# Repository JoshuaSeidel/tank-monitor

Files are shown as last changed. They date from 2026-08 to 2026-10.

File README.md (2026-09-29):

# Tank Monitor

An ESP32-C6 aquarium controller: water temperature, TDS, and light level, with a
**self-learning predictive thermostat** that drives a heater and a cooling fan.
Reports to Home Assistant over MQTT with auto-discovery.

The control loop runs entirely on the ESP32. Home Assistant gets the data and
a setpoint slider, but if HA reboots, updates, or falls off the network, the
tank keeps being regulated exactly as before.

---

## Why the temperature swings 73–76 °F

A stock aquarium heater is a bimetallic on/off switch with roughly 2 °F of
hysteresis. It heats until it's over target, shuts off, the tank coasts down
past target, and it kicks on again. Add the daylight/lights heat load on top
and you get the 3 °F band you're seeing.

Two things here fix that:

1. **Time-proportional output.** Instead of on/off, the heater is switched on
   for a fraction of each 15-minute window. 30% duty is 30% of full heater
   power, so the tank can sit *at* the setpoint instead of oscillating around
   it. (Set the heater's own thermostat dial to its maximum and let this
   control it — the heater becomes a dumb resistor.)

2. **Feed-forward from a learned model.** The controller knows how fast your
   specific tank heats, cools, and gains heat from the lights, so it backs the
   heater off *before* the lights warm the water rather than after.

Expect ±0.5 °F once the model has a day of data — or ±0.2 °F if you swap the
heater onto an SSR and shorten the window (see below).

---

## Board

Built for a **LAFVIN / Waveshare ESP32-C6-LCD-1.47** — ESP32-C6 with an
on-board 1.47" 172x320 ST7789V panel. ESPHome ships a preset for this exact
board (`model: WAVESHARE-ESP32-C6-LCD-1.47`), which supplies the panel's
CS/DC/reset pins, its 34 px column offset, and colour inversion.

The display driver is `mipi_spi`, not the older `st7789v` platform. With a
90 degree rotation the old driver wants a full framebuffer and the C6 — 512 KB
SRAM, no PSRAM — runs out of memory. Current build sits at **35% RAM, 66%
flash**, so there's headroom but not unlimited.

The screen shows water temperature, target, heater and fan duty bars, TDS,
light level, and controller state. It keeps working when Home Assistant
doesn't, which is the whole point of running the control loop on-device.

### Pins already taken by the board

The LAFVIN breaks out two header rows, and **only these pins are physically
available**:

| Edge | Pins |
|---|---|
| One long edge | `9, 18, 19, 20, 23, 22, 13, RX, TX` |
| Other long edge | `5, 4, 3, 2, 1, 0, 3V3, GND, 5V` |

**GPIO10 is not on the board** — anything assigned to it silently does
nothing. Avoid `22` as well (exposed, but it's also the LCD backlight net),
`13` (USB D+), and `9` (boot strapping pin). GPIO6/7 are the LCD SPI bus and
14/15/21 are its CS/DC/reset, none of which reach a header.

## Parts list

Manufacturer links are verified. Amazon entries are **searches**, not
specific listings — ASINs for commodity parts churn constantly and a dead
link is worse than none.

### Required — the controller

| Part | Notes | Where |
|---|---|---|
| **LAFVIN / Waveshare ESP32-C6-LCD-1.47** | the controller and its display. Any ESP32 works — see `boards/` | [search](https://www.amazon.com/s?k=ESP32-C6+1.47+inch+LCD+development+board) |
| **DS18B20 waterproof probe** | water temperature. The one measurement the whole control loop depends on | [search](https://www.amazon.com/s?k=DS18B20+waterproof+temperature+probe) |
| **4.7 kΩ resistor, ¼ W** | **required** pull-up for the DS18B20, and the one part that arrives in none of the boxes | [assortment kit](https://www.amazon.com/Resistor-Assortment-Resistance-Electric-Projects/dp/B07N1ZK8CC) |
| **CZH-Labs D-1584TL** | 2-channel relay outlet module, ~$49. Two *independently* switched outlets — a single-channel IoT Relay cannot run a heater and a fan | [Amazon](https://www.amazon.com/Two-Channel-Control-Module-Arduino-Raspberry/dp/B0GR85JF68) · [direct](https://czh-labs.com/products/ac-power-2-channel-iot-relay-outlet-module-din-rail-or-screw-mounting) |
| 26–28 AWG stranded wire | hookup, silicone jacket is easiest | [search](https://www.amazon.com/s?k=26+AWG+silicone+stranded+hookup+wire) |
| Heat shrink, 2 mm and 3 mm | joints and splices | [search](https://www.amazon.com/s?k=heat+shrink+tubing+assortment+2mm+3mm) |

### Strongly recommended — pH

The controller cannot regulate what it cannot measure, and pH is the number
that tells you whether CO₂ is safe. **Buy the industrial version**: the
standard Gravity kit's electrode is not rated for permanent immersion, which
DFRobot themselves will tell you if you ask.

| Part | Notes | Where |
|---|---|---|
| **DFRobot SEN0169-V2**, *wide voltage* edition | $64.90. 3.3–5.5 V supply and **0–3 V output** — the classic edition outputs 0–5 V and would damage an ESP32 ADC pin | [DFRobot](https://www.dfrobot.com/product-2069.html) · [wiki](https://wiki.dfrobot.com/sen0169-v2/) |
| **pH 4.00 / 6.86 / 9.18 buffer sachets** (the NIST set) | the sensor is meaningless uncalibrated. Calibrate on the two that bracket the tank (9.18 and 6.86), check against the third | [search](https://www.amazon.com/s?k=pH+4.00+6.86+9.18+calibration+buffer+solution+sachets) |
| **KCl storage solution** | the electrode must never dry out. A dried probe is a dead probe | [search](https://www.amazon.com/s?k=pH+probe+KCl+storage+solution) |
| Suction-cup probe holder | fixes angle and depth; the bulb must point down | [search](https://www.amazon.com/s?k=aquarium+pH+probe+holder+suction+cup) |

### Optional — the rest

| Part | What it buys you | Where |
|---|---|---|
| Keyestudio TDS meter | dissolved solids. Useful for *trend*, not absolute — it ships uncalibrated | [search](https://www.amazon.com/s?k=Keyestudio+TDS+meter+sensor) |
| GY-302 / BH1750 module | ambient light, which the model uses to pre-compensate for the lights' heat | [search](https://www.amazon.com/s?k=GY-302+BH1750+light+sensor+module) |
| ESP32-2432S028R "CYD" | a second board as a remote touch panel — see `boards/cyd-esp32-2432s028r.yaml` | [search](https://www.amazon.com/s?k=ESP32-2432S028R+CYD+2.8+inch+display) |
| Seachem Ammonia Alert | a passive colorimetric disc, ~$10, lasts a year. **The best value item on this page** — there is no usable electronic ammonia sensor for a tank | [search](https://www.amazon.com/s?k=Seachem+Ammonia+Alert) |
| TCS34725 colour sensor | reads that disc so the ESP32 can log and alarm on it | [search](https://www.amazon.com/s?k=TCS34725+RGB+color+sensor) |
| DFRobot ORP probe | oxidation-reduction potential — the only practical measure of dissolved organic load. `GPIO33` is reserved for it on the WROOM-32 board, `GPIO4` on the S3 | [DFRobot](https://www.dfrobot.com/product-1071.html) |

### Test kits you cannot skip

No electronic sensor replaces these, and this project has twice chased a
phantom because a continuous reading was trusted over a liquid test.

| Kit | For |
|---|---|
| **API Freshwater Master Test Kit** | pH (low **and** high range), ammonia, nitrite, nitrate |
| **API GH & KH Test Kit** | sold separately. KH is what makes CO₂ injection safe or unsafe |

Test strips read GH and KH low and cannot resolve the range that matters
here. Use the drop tests.

### About the 4.7 kΩ resistor

**Anything from 2.2 kΩ to 10 kΩ works** — 4.7 kΩ is convention, not a
requirement. Check your DS18B20 first: some waterproof probes ship with a
small adapter board that already has one.

**If you don't have one yet**, the C6's internal pull-up will get you
through a bench test. Replace the `one_wire` block with:

```yaml
one_wire:
  - platform: gpio
    pin:
      number: GPIO18
      mode:
        input: true
        output: true
        open_drain: true
        pullup: true
```

It is roughly 45 kΩ, ten times weaker than spec. Fine on a short lead on the
bench; on a long waterproof probe cable it gives intermittent dropouts, which
this firmware reads as a probe fault and answers by cutting the heater.

## Wiring

Everything runs at 3.3 V.

### DS18B20 water temperature — 1-Wire

| Probe wire  | ESP32  |
|---|---|
| Red (VDD) | 3V3 |
| Black (GND) | GND |
| Yellow (DQ) | GPIO18 |

Add a **4.7 kΩ resistor between DQ and 3V3**. Not optional — the bus is
open-drain and reads garbage without it.

### Keyestudio TDS meter — analog

| Board pin | ESP32  |
|---|---|
| VCC | 3V3 |
| GND | GND |
| A (out) | GPIO1  |

Power the board at **3.3 V, not 5 V**. Feeding a 5 V-powered board's output
into a GPIO will damage the pin. If you must run it at 5 V, put a 10k/20k
divider on the output.

The C6 has a single ADC unit, so the classic ESP32 problem where ADC2 stops
working while Wi-Fi is up doesn't apply here. GPIO0 is the only other free
ADC pin — GPIO2 and GPIO3 now drive the relays, and the rest of the ADC
block (GPIO4-6) is taken by the microSD slot and LCD.

### GY-302 / BH1750 light sensor — I²C

| Module pin | ESP32 |
|---|---|
| VCC | 3V3 |
| GND | GND |
| SDA | GPIO19  |
| SCL | GPIO20  |
| ADDR | leave unconnected (address 0x23) |

Mount it where it sees the tank lighting *and* the room's daylight, but not
where it's shadowed by the hood at some hours and not others — the controller
learns a 24-hour light profile and a moving shadow shows up as fake noise.

Since your lights are touch-switched rather than scheduled, this sensor is
what tells the controller they're on. It learns their typical schedule too,
so it anticipates them; if you turn them on off-schedule, the live reading
still feeds the model within one control tick.

### Heater and fan — 2-channel relay outlet module

Built around the **CZH-Labs D-1584TL**, a 2-channel IoT relay outlet module
(~$49). Two optocoupled, electrically isolated control inputs, a NEMA 5-15P
cord, and a normally-off + normally-on NEMA 5-15R receptacle per channel.
10 A per outlet, 15 A total. No mains wiring on your part.

| Module terminal | ESP32  |
|---|---|
| Channel 1 IN+ | GPIO2 (heater)  |
| Channel 2 IN+ | GPIO3 (fan) |
| IN− (both) | GND |

Plug the heater into channel 1's **normally-off** receptacle and the fan into
channel 2's normally-off receptacle. Inputs are active high, so no `inverted:`
in the pin config.

**Set the heater's own thermostat dial to maximum.** This controller replaces
it; the heater becomes a dumb resistive element. Leaving the dial at a
setpoint means the heater's 2 °F hysteresis is still in the loop.

Two caveats:

- **3.3 V is at the bottom edge of the module's 3–120 VDC input range.** It
  should latch fine, but there's little margin. If a channel chatters, drive
  the input from the ESP32's 5 V pin through a small NPN transistor instead of
  straight off the GPIO.
- **These are mechanical relays**, which is why the window is 900 s and not
  300 s. At 5-minute windows you'd spend ~288 contact cycles a day and wear
  them out in about a year; at 15 minutes it's ~96/day, so several years. The
  controller doesn't cycle at all when duty is pinned at 0% or 100%.

**If you want the tighter ±0.2 °F band later:** move the heater to a
zero-crossing SSR (SSR-25DA class, 3–32 VDC control, ~$12) in a project box,
and set `heater_output`'s `period` back to `300s`. An SSR is silent, has no
contacts, and cycles indefinitely — but it's real mains wiring, so only take
that on if you're comfortable with it and feeding it from a GFCI outlet. You
want the tank on a GFCI regardless.

### Full wiring diagram

All three sensors need 3V3 and GND, and the relay needs ground too — seven
power wires converging on two pads. Everything solders directly to the board:
join the power wires in a splice off-board and run one pigtail to each pad.
See [ASSEMBLY.md](ASSEMBLY.md).

Total sensor draw is under 10 mA, so the board's own regulator powers
everything. No external supply.

**Power — one pigtail per pad, split at a soldered splice:**

```
   ESP32-C6-LCD-1.47                        ┌── DS18B20 red
   ┌─────────────┐                          │
   │             │            ╔═══════╗     ├── TDS VCC
   │        3V3 ●┼────────────╢ splice╟─────┤
   │             │            ╚═══════╝     └── BH1750 VCC
   │             │
   │             │            ╔═══════╗     ┌── DS18B20 black
   │        GND ●┼────────────╢ splice╟─────┤
   │             │            ╚═══════╝     ├── TDS GND
   └─────────────┘                          │
                                            ├── BH1750 GND
                                            │
                                            └── Relay IN- (both ch.)
```

**Signal — one wire each, straight to its GPIO:**

```
   ESP32-C6-LCD-1.47
   ┌─────────────┐
   │             │
   │      GPIO18 ●──────────┬──────────────► DS18B20  DQ   (yellow)
   │             │          │
   │             │         ┌┴┐
   │             │         │ │ 4.7k  pull-up, at the BOARD end
   │             │         └┬┘        not out at the probe
   │        3V3 ─┼──────────┘
   │             │
   │       GPIO1 ●─────────────────────────► TDS       A    (analog)
   │             │
   │      GPIO19 ●─────────────────────────► BH1750    SDA
   │      GPIO20 ●─────────────────────────► BH1750    SCL
   │             │                           BH1750    ADDR → leave open
   │             │
   │       GPIO2 ●─────────────────────────► D-1584TL  CH1 IN+  (heater)
   │       GPIO3 ●─────────────────────────► D-1584TL  CH2 IN+  (fan)
   │             │
   └─────────────┘
```

**Every wire, in one table:**

| From (ESP32-C6) | To | Notes |
|---|---|---|
| 3V3 | bus → DS18B20 red, TDS VCC, BH1750 VCC | TDS at 3.3 V, **never 5 V** |
| GND | bus → DS18B20 black, TDS GND, BH1750 GND, relay IN− ×2 | one common ground |
| GPIO18 | DS18B20 yellow (DQ) | + 4.7 kΩ from DQ to 3V3 |
| GPIO1 | TDS "A" | ADC-capable pin |
| GPIO19 | BH1750 SDA | |
| GPIO20 | BH1750 SCL | |
| GPIO2 | D-1584TL channel 1 IN+ | heater |
| GPIO3 | D-1584TL channel 2 IN+ | fan |

Not wired: BH1750 `ADDR` (leave floating for address 0x23), and the relay
module's mains side — it has its own NEMA 5-15P cord.

**Routing matters for one wire in particular.** The TDS line is a
high-impedance analog signal; run it alongside the relay module's power cord
and it will pick up 60 Hz hum. Keep those separated. If the BH1750 sits more
than roughly a foot from the board, add a 100 nF cap across its VCC/GND at
the sensor end.

## The display

**One screen. The temperature owns almost all of it.**

The panel is 1.47" diagonal at 320x172, which in landscape is about
**33 x 18 mm** — a pixel pitch of roughly 0.10 mm. To read a number at 8 ft
you need digits subtending ~15-20 arcminutes, which works out to **11 mm
tall**. That is nearly the full height of the panel, so the temperature gets
everything and nothing else competes with it.

The font is sized to that constraint, not to taste. At 150 px em, "74.5"
measures **306 px wide by 109 px tall** — the largest it can be and still fit
320 px across. 160 px overflows. 109 px is 11.2 mm, which subtends ~16
arcmin at 8 ft and ~25 arcmin at 5 ft.

```
┌────────────────────────────────────────────┐
│ LIGHT 820                       lights on  │  ← 26px, amber when lit
├────────────────────────────────────────────┤
│              74.5                          │  ← 9.7mm digits
│                                            │    background = status colour
│ STEADY            74-75 | sw 0.2 | heat 32%│  ← status row
├────────────────────────────────────────────┤
│ TDS 212                          TDS OK    │  ← 32px strip
└────────────────────────────────────────────┘
```

172 px of panel, divided: **26 light / 114 temperature / 32 TDS**.

**Every string is positioned by its baseline, not its top or bottom.** This
matters more than it sounds: ESPHome places text using the font's *line box*
— ascender to descender, 148 px at this size — while the digits themselves
are only 92 px of ink. Anchoring `TOP_CENTER` therefore drops the glyphs
~28 px lower than the coordinate suggests, which is exactly how the first
attempt ended up printing the temperature through the status row. The
baseline is where digits physically rest, so it's the one anchor that
doesn't depend on font metrics.

At 126 px em the digits occupy y 28–120, clear of the light strip above
(ends at 26) and the status row below (ink starts at 126).

**The light strip costs the temperature ~1 mm of digit height** — 11 mm down
to 9.7 mm, which is ~13 arcmin at 8 ft instead of ~16. Still readable at
that range, slightly less comfortable. Delete the strip and bump `font_huge`
back to 150 if you'd rather have the height.

The strip goes **amber when the tank lights are on** (above `light_on_lux`,
default 50 lx) and near-black when they're off. Since the controller
pre-compensates for the lights' heat load, seeing their real state next to
the temperature is worth the space.

**From across the room you read the background colour, not the text.** Green,
amber, red — that alone tells you whether the tank is holding. The digits are
readable at 5-8 ft. Everything else (target band, hourly swing, heater duty,
TDS status) is deliberately small: it's there when you walk up to it, and
it's on the Home Assistant dashboard when you want to actually study it.

Temperatures of 100 °F or above drop the decimal so the digits still fit. If
you ever see that, the decimal place is not your problem.

### Thresholds

Set to your targets. Green inside the band, amber just outside, red beyond:

| | Green | Amber | Red |
|---|---|---|---|
| **Temperature** | 74–75 °F **and** steady | 73.5–74, 75–75.5 °F, or `SWINGING` | below 73.5, above 75.5 |
| **TDS** | 180–250 ppm | 150–180, 250–300 ppm | below 150, above 300 |

**Green requires the tank to be steady, not just momentarily in band.** The
controller keeps an hour of temperature history and reports peak-to-peak
swing; if that exceeds `temp_swing_max` (0.5 °F) the screen shows amber and
`SWINGING` even when the current reading sits inside 74–75. A tank crossing
through the band on its way between 73 and 76 is not holding temperature, and
the display shouldn't claim it is.

Swing reads `--` for the first ten minutes after a boot, and doesn't block
green until there's enough history to mean something.

All six numbers are substitutions at the top of `packages/base.yaml`
(`temp_lo`, `temp_hi`, `temp_red_lo`, `temp_red_hi`, `tds_lo`, `tds_hi`,
`tds_red_lo`, `tds_red_hi`) — change them in one place and both the display
bands and the on-screen target text follow.

The control setpoint is **74.5 °F**, the centre of the 74–75 band,
so normal drift stays inside green in both directions.

### Not measured

Your target list also includes pH 7.2–7.5, GH 7–8, and KH 3–4. There's no
sensor for those in this build — GH and KH have no practical hobby-grade
probe and stay test-kit measurements. pH *is* addable (an analog probe on a
spare ADC pin, GPIO0/2/3 are free), but it needs two-point calibration and
the probe is a consumable that drifts and needs replacing every year or so.
Say the word if you want it.

## 3D printed case

**Nothing off the shelf fits this board.** The Waveshare-outline cases and
the generic MakerWorld ESP32-C6 enclosure both assume the LCD is centred with
USB on a long edge; the LAFVIN is a stick, with USB-C, BOOT and RESET all on
one short end.

So there's a purpose-built one in [`case/`](case/) — parametric OpenSCAD plus
ready STLs, with a cable exit for the eight wires this build has. Print the
fit-test coupon first: LAFVIN publishes no mechanical drawing, so the
dimensions came off photographs and are good to about ±1 mm.

See [case/README.md](case/README.md).

## Assembly

Step-by-step soldering instructions are in **[ASSEMBLY.md](ASSEMBLY.md)** —
build order, the pull-up resistor, the pre-power checks, and a staged
power-up sequence.

## Flashing

### Build straight from git (recommended)

Rather than pasting the config into the ESPHome dashboard and re-pasting it
after every change, put **`tank-monitor-remote.yaml`** there instead — a
short wrapper that pulls the whole config from this repo:

```yaml
packages:
  tank_monitor:
    url: https://github.com/JoshuaSeidel/tank-monitor
    ref: main
    files:
      - packages/base.yaml
      - packages/control.yaml
      - packages/sensors.yaml
      - boards/lafvin-esp32c6.yaml
    refresh: 0s
```

Save it in the dashboard as `tank-monitor.yaml`. After that, a push to
`main` is all it takes — the next install builds the new config.

That `files:` list *is* the configuration, and it is where you choose
hardware — see [Config layout](#config-layout) below.

**`refresh: 0s` is not optional.** The default is `1d`, so without it you
can push a fix and spend an afternoon flashing yesterday's config.

Only `secrets.yaml` stays local. `!secret` references inside the remote
file resolve against your local secrets, so nothing sensitive goes in git.

**Local overrides win over the package**, so device-specific tweaks don't
require forking. Adding this below the `packages:` block sets the target to
75 °F for this device only:

```yaml
substitutions:
  target_temp_f: "75.0"
```

The `tank_controller` component is fetched from git the same way, so this
builds in the **Home Assistant ESPHome add-on** with no local files at all.

Locally instead:

```sh
pip install esphome
cp secrets.yaml.example secrets.yaml   # then edit it
esphome run tank-monitor-remote.yaml
```

### Config layout

The config is split so the board is the only thing that changes between
builds. Nothing under `packages/` names a GPIO; everything that does lives
in `boards/`.

| File | Holds |
| --- | --- |
| `packages/base.yaml` | Identity, Wi-Fi, OTA, MQTT, SNTP, the display palette, the tuning substitutions |
| `packages/control.yaml` | The `tank_controller` component and every entity derived from it |
| `packages/sensors.yaml` | DS18B20, BH1750 and the TDS maths — expressed without pins |
| `packages/ph.yaml` | The pH maths and its two-point calibration — also without pins |
| `boards/lafvin-esp32c6.yaml` | LAFVIN ESP32-C6, 1.47" 172×320 ST7789V |
| `boards/cyd-esp32-2432s028r.yaml` | "CYD" ESP32-2432S028R, 2.8" 240×320 ILI9341 + touch |
| `boards/esp32-wroom32.yaml` | Plain ESP32-WROOM-32 devkit, headless |
| `boards/esp32s3-mini.yaml` | ESP32-S3-Zero / "S3 SuperMini", headless, 23×18 mm |

The board file supplies the buses and ids the shared packages expect —
`tds_voltage`, `ph_voltage`, `heater_output`, `fan_output`, plus the
`one_wire` and `i2c` buses — so a new board is one new file in `boards/`
and one changed line in the wrapper. A change to the control loop lands on
every board from one push.

Files are merged in listed order and later entries win, so the board file
gets the last word. That is how the CYD file switches serial logging off
without `packages/base.yaml` knowing anything about it.

### Building for the CYD instead

`tank-monitor-cyd-remote.yaml` is the same wrapper with the last line
pointing at `boards/cyd-esp32-2432s028r.yaml`. That board is far more
pin-constrained than the C6 — the full reasoning and the wire-by-wire pin
budget are in the header comment of the board file. Two things worth
knowing before ordering parts:

- Its I²C runs on the UART pins, so the board is **OTA-only** (no serial
  console) and the **first USB flash must be done with the BH1750
  unplugged** — the CH340 talks to the ESP32 over those same pins.
- Nothing on the board brings 5 V out to a connector, so the relay module
  needs its own supply, sharing ground with the board. The D-1584TL's
  optocoupled inputs are designed for exactly that.
- **"CYD" is several different boards.** They differ in display controller,
  and the seller's listing is not reliable evidence. The board file uses
  ESPHome's `ESP32-2432S028` preset (ILI9341, what the listing claims); if
  the panel comes up blank, garbled or colour-inverted, swap that one string
  for `ESP32-2432S028-7789` (ST7789V) or `ESP32-2432S028-9342` (ILI9342).

It uses the `mipi_spi` driver rather than `ili9xxx`, which is a RAM decision
rather than a stylistic one. A full 320×240×2 = 154 kB framebuffer does not
fit on a no-PSRAM ESP32 once statics are placed — `ili9xxx` allocates it in
one shot with no partial-buffer mode, and on failure calls `mark_failed()`,
so the screen silently never appears while everything else runs. `mipi_spi`
renders in stripes at `buffer_size: 50%`, and makes the controller swap above
a one-line change.

### Web interface

Every build serves its own UI at the device's IP — no Home Assistant, no
internet, no CDN. ESPHome's page is only `<esp-app></esp-app>` plus one
script tag, so pointing `js_url` at the device's own `/tank.js` replaces its
CDN bundle and
`components/tank_webui/assets/tank.js` becomes the whole interface. State
arrives over `/events`; controls POST back to the REST endpoints
`web_server` already exposes, addressed by the id each entity reported on
`/events` — its display name, e.g. `/number/Cal%20pH%20High%20Value/set`.
Since ESPHome 2026.7 those routes match by name only; the old object-id form
(`/number/cal_ph_high_value/set`) returns 404. A control stays disabled until
its entity has reported, so a board without one (no backlight, no pH) never
posts to an address that does not exist.

**Nothing to copy.** The script and stylesheet live inside the
`tank_webui` external component, which git delivers in full — unlike
`js_include`, which reads from the ESPHome config directory and cannot be
supplied by a remote package. The component embeds them at build time and
serves them at `/tank.js` and `/tank.css`, so `js_url` points at the
device itself.

Push, rebuild, done — same as every other change here.

It shows temperature with the same band colours as the panels, the target
with steppers, heater and fan duty plus live relay state, swing, TDS, pH,
light, model confidence, and the water chemistry mirrored from Home
Assistant with its age. Controls: setpoint, adaptive learning, backlight,
restart, reset learning — **and the full calibration panel** (see below).

The chemistry card hides itself on boards that don't include
`packages/chemistry.yaml`, rather than showing six dashes; the pH and
calibration cards do the same on boards without `packages/ph.yaml` or
`packages/sensors.yaml`.

### Secrets

The add-on shares **one** `secrets.yaml` across every device, so anything
device-specific is prefixed to avoid collisions:

| Key | Scope |
|---|---|
| `wifi_ssid`, `wifi_password`, `mqtt_broker` | shared with your other devices |
| `tank_monitor_mqtt_username` | this device |
| `tank_monitor_mqtt_password` | this device |
| `tank_monitor_ota_password` | this device |
| `tank_monitor_ap_password` | this device |

Give this device its own MQTT user rather than reusing a shared one — it
keeps broker access auditable and makes the logs readable when something
misbehaves.

First flash over USB; after that `esphome run` uses OTA. Live values are at
`http://tank-monitor.local/`.

---

## How the learning works

The controller fits a five-parameter thermal model of your tank:

```
dT/dt  =  kh·heater  −  kf·fan  −  ka·(T − ref)  +  kl·light  +  c
```

**Everything you configure or read is Fahrenheit.** The model itself runs in
Celsius internally — not from preference, but because its priors, clamps and
residual guards are tuned in °C/min, and hand-converting those constants is
how a working controller quietly stops working. The component converts once
at its boundary; no Celsius value is published or configurable.

- `kh` — how fast your heater actually raises this volume of water
- `kf` — how much your fan's evaporative cooling pulls out
- `ka` — how fast the tank loses heat to the room per degree of difference
- `kl` — heat the lights add at full brightness
- `c`  — residual constant drift

Parameters are fit online with recursive least squares (forgetting factor
0.9995 — it adapts over days, not minutes) and clamped to physically plausible
ranges, which is what keeps closed-loop identification from wandering off
during long stretches where nothing much is changing.

**Learning runs on 5-minute windows, not every tick.** A DS18B20 quantizes to
0.1125 °F; differentiating that every 30 s produces noise far larger than the
~2 °F/hour signal being measured. Averaging over 5 minutes brings it into
range.

Separately, a 96-slot (15-minute resolution) profile of normalized light level
is learned per time-of-day, so the controller can predict the light heat load
20 minutes ahead and pre-compensate.

Both the model and the light profile are saved to flash every 10 minutes and
restored on boot — a reboot doesn't cost you the learning.

### If the temperature stops updating

The 1-Wire bus is **scanned once, at boot**. If the DS18B20 isn't detected
during startup, ESPHome never retries — the probe stays dead until the next
reboot, even if you fix the wiring while it's running. Look for this in the
logs:

```
[W][gpio.one_wire]:   Found no devices!
[W][dallas.temp.sensor]:   Unable to select an address
```

versus a healthy boot, which prints the probe's 64-bit address.

Checks, with the board powered off:

| Measure | Expect |
|---|---|
| DQ (GPIO18) to 3V3 | ~4.7 kΩ — the pull-up bridge |
| DQ to GND | open |
| 3V3 to GND | open |
| Probe VCC to 3V3 | ~0 Ω |

Then **reboot** — fixing the wiring alone won't bring it back.

Note that the `Temperature Fault` binary sensor and the on-device display
are the authoritative indicators. The temperature sensor itself simply stops
publishing, so anything reading it goes unavailable rather than showing a
stale number.

### What can go wrong, and what catches it

| Failure | Caught by | Response |
|---|---|---|
| Probe stops responding | controller, after 120 s | heater cut, `Temperature Fault`, HA alert |
| Probe reads wrong but plausible | **Nothing.** There is no second temperature probe — verify against a reference thermometer by hand | — |
| Heater dead, unplugged, or relay channel not wired | `Heater Not Responding`, after 45 min at full duty with no rise | HA alert; the tank is drifting cold |
| Heater stuck on | hard `max_temperature` cutout, then HA runaway alarm | heater off, fan full |
| Controller offline entirely | HA sees the MQTT status go offline | HA alert |
| Wi-Fi or HA down | nothing needed | control loop is on-device and unaffected |
| Learned model goes wrong | feedforward is weighted by confidence | falls back toward plain feedback |

`Heater Not Responding` is the one that would have caught the GPIO10
mistake — the fan channel was assigned to a pin that isn't broken out, so
it would have run at 0% forever with nothing to say so.

### Safety behavior

- Above `max_temperature` (82 °F): heater off, fan full, model ignored.
- Below `min_temperature` (68 °F): heater full.
- Temperature probe missing for 2 minutes: **heater cut off** and the
  `Temperature Fault` problem sensor trips. A slowly cooling tank is a much
  better failure than a cooked one.
- Residuals over 54 °F/hour are discarded rather than learned from — that's a
  water change or a bad read, not information about the tank.

---

## Long-term history and Grafana

Home Assistant records everything here to **InfluxDB 3** (the InfluxDB3 App,
Enterprise with a free At-Home licence). The integration is configured through
the UI — Settings → Devices & Services → InfluxDB — not YAML.

Settings that work with this App:

| Field | Value |
|---|---|
| API | v2 (`configure_v2` in the flow) |
| URL | `http://32b8266a-influxdb3:8181` |
| Verify SSL | off |
| Organization | anything — InfluxDB 3 requires the field but ignores it |
| Bucket | `homeassistant` — on v3 this is the *database* name |

**Use `http`, not `https`.** The App sets `ssl: true` by default but ships no
certificate files, so it serves plaintext; TLS fails with
`WRONG_VERSION_NUMBER`.

Grafana lives in [`grafana/`](grafana/) — an importable dashboard plus
datasource setup. See [grafana/README.md](grafana/README.md).

## Asking the tank questions (Tank MCP)

[`tank-mcp/`](tank-mcp/) is a Home Assistant App that serves an **MCP server**
for this tank: an AI assistant gets tools for the controller,
manual test entry, and a record of fish and shrimp lost — plus the ability to
say any of it out loud on an Echo.

It is deliberately not a general Home Assistant bridge. Every tool answers a
tank question and answers it with a verdict attached, using thresholds set for
*this* stock (73.4 °F cold floor for the loaches, 0.02 mg/L free ammonia,
GH/KH read live from the target helpers rather than hard-coded).

Install it by adding this repository under **Settings → Apps → Store → ⋮ →
Repositories**. Full documentation, tool list, and the Alexa routine setup are
in [tank-mcp/DOCS.md](tank-mcp/DOCS.md).

Two things it adds on the Home Assistant side:

- An **Aquarium Livestock** device, published over MQTT discovery — total
  alive, losses over 7 and 30 days, days since the last one, with the
  per-species breakdown as attributes.
- `script.aquarium_speak_status`, which builds the spoken report from Home
  Assistant state alone. That is the ask-out-loud path: Alexa cannot call MCP,
  so exposing this script to Alexa and pointing a routine at it is what makes
  "Alexa, tank report" work.

## Home Assistant entities

Under one `Tank Monitor` device:

**Controls** — `Target Temperature` (°F, 70–80), `Display Backlight`,
`Adaptive Learning` switch,
`Reset Learning` button, `Restart` button.

**Main** — `Water Temperature` (°F), `TDS` (ppm),
`Electrical Conductivity` (µS/cm), `Tank Light Level` (lx), `Heater Output`
(%), `Fan Output` (%), `Predicted Temperature (15 min)`, `Controller State`.

**Diagnostic** — `Model Confidence`, `Model Bias`, `Tank Time Constant`,
`Learned Heater Power`, `Learned Light Heat Gain`, `Predicted Light Load`,
`Learned Fan Power`, `Temperature Drift Rate`, `TDS Probe Voltage`,
`Temperature Fault`, `Heater Not Responding`, `Fan Not Responding`,
Wi-Fi signal, uptime, IP.

There is no `Target Temperature` *sensor* — the `Target Temperature` number
under Controls is the setpoint, and it is recorded to InfluxDB like any other
entity, so Grafana draws the setpoint line straight from
`number.tank_monitor_target_temperature`. A mirror sensor would have been a
second entity with the same name and the same value.

No entity name carries a `°F` suffix. Every temperature in this project is
Fahrenheit, so the unit is not a distinguishing feature — see
[Tuning](#tuning).

`Model Confidence` reaching 100% means roughly a day of learning steps have
accumulated. Watch `Heater Output` — once settled it should sit at a fairly
steady partial value, not flip between 0 and 100.

### `Heater Output` and `Fan Output` are commands, not measurements

Both are the controller reading back its own decision. There is no current
sensing on either channel and nothing confirms the relay closed, or that
anything is plugged into that outlet. `Fan Output: 100%` means "over the next
900 seconds I intend to hold Ch2 closed the whole time", nothing more. They
are standard controller-output terms, but they carry a `%` and a
`state_class: measurement`, so it is easy to read them as evidence.

They are not evidence, and this has already cost an evening: a heater that
had stopped delivering heat showed 90–97% on that graph the entire time it
was failing. What caught it was the water falling while the model said it
should be climbing.

The entities that actually reflect delivery are inferred from how the water
responded:

| Entity | Says |
| --- | --- |
| `Learned Heater Power` (°F/h) | how much the heater really adds at 100% |
| `Learned Fan Power` (°F/h) | the same for the fan; near its floor after real runtime means it is not cooling |
| `Heater Not Responding` | ≥90% commanded for 45 min with no rise |
| `Fan Not Responding` | ≥90% commanded for 45 min with no fall |

The two "Not Responding" checks are coarse — they catch an absent actuator,
not a weak one. Use the learned gains for that.

---

## Calibration

**Every correction lives on the device, in flash, and is applied before the
value is published.** Not in Home Assistant, and not in a substitution that
needs a reflash.

Both of those alternatives were tried and both were wrong. A substitution
means recalibrating is a config edit and a rebuild — precisely what you
cannot do standing at a sink with a wet probe. And a correction applied in
Home Assistant is a correction the tank does not have: the ESP-NOW panel and
this device's own web page would still be showing the uncorrected number, and
the three surfaces would disagree.

So the numbers are `restore_value` globals, they survive reboots and OTA
updates, and they are reachable **two** ways — Home Assistant, and the
device's own web page at its IP. The second one is the one that matters,
because it still works with the broker, the router and HA all down.

### TDS — single point

1. Bring the calibration solution **to tank temperature**. Conductivity moves
   about 2 %/°C, so a bottle straight off a cold shelf bakes several percent
   of error into K permanently, and it will read wrong ever after in a way
   that is very hard to trace back.
2. Set **Cal TDS Standard** to what the bottle says (342 ppm and 1000 ppm are
   the usual ones).
3. Stand the probe in it and watch **TDS** settle — the single sample
   Calibrate TDS solves against, which the device page shows as *Reading
   now*. Not `TDS 1h Mean`: that is still an hour of tank water.
4. Press **Calibrate TDS**.

It solves `k = k · standard / reading` and refuses any result outside
0.1–5.0, which is the range beyond which the probe, not the calibration, is
the problem. **Cal TDS K Factor** is also directly editable if you would
rather type a known value.

### pH — two point

The two points are named for their role, not a number: **Cal pH High Value**
and **Cal pH Low Value** hold what each buffer actually says. Choose a pair
that **brackets the tank**. A glass electrode is linear from about 4 to 10,
so a third point buys nothing — but a tank at 7.4 calibrated on 6.86 and 4.00
is extrapolated above its highest point, which is where slope error hurts
most. With the NIST set (4.00 / 6.86 / 9.18) that means calibrating on 9.18
and 6.86 and keeping 4.00 back as the check.

1. Set **Cal pH High Value** and **Cal pH Low Value** to what the two bottles
   say.
2. Rinse in distilled water and **blot** dry. Never wipe the glass bulb: it
   builds a static charge that takes minutes to bleed off, and the reading
   wanders the whole time.
3. Stand in the high buffer, wait two minutes, press **Capture High Point**.
4. Rinse, blot, stand in the low buffer, wait two minutes, press
   **Capture Low Point**.
5. Rinse, blot, stand in the third buffer and read **Water pH**. Within about
   0.1 means the electrode is linear and healthy. Never calibrate on the check
   buffer — that is what makes it independent evidence rather than a
   restatement of the calibration.

On the device's own page the capture buttons carry the configured value
(**Capture high 9.18**), so the bottle in your hand can be checked against the
label before anything is stored. **Cal pH High Voltage** and **Cal pH Low
Voltage** show what was captured — write them down, and a point that has
drifted is obvious next time.

**Cal pH Slope** is the check that matters. It reads negative on this board —
more volts, lower pH — and a healthy electrode sits near −0.177 V/pH (the
Nernst slope at 25 °C); the device's page shows the magnitude. Much below
about 0.150 in size and it is worn out — recalibrating a dead electrode just
moves where it is wrong.

The reading is temperature-corrected against the DS18B20 at runtime, so a
probe calibrated at room temperature still reads correctly at 74 °F.

### Temperature — offset

**Cal Temperature Offset**, in °F, against a reference thermometer. Worth
doing: this probe is the only one the control loop has, so if it reads low
the heater will happily cook the tank while reporting the target, and nothing
anywhere will notice.

The offset is applied to the internal Celsius sensor rather than the
published Fahrenheit one, deliberately — the controller reads the internal
one, so correcting anywhere else would leave the control loop working from
the uncorrected value while every display showed the corrected one.

## Tuning

At the top of `packages/base.yaml`:

- **`target_temp_f`** — the setpoint, in Fahrenheit. Everything you set or
  read is Fahrenheit; the controller converts to Celsius once, internally,
  because its priors and clamps are tuned in °C/min.
- **`tds_k_factor`** — put the TDS probe in a known standard (707 ppm /
  1413 µS/cm), let it settle, set this to `known_ppm / displayed_ppm`,
  re-flash. Check `TDS Probe Voltage` if a reading looks wrong; in air it
  should sit near 0 V.

In the `tank_controller:` block:

- **`response_time`** (default 30 min) — how hard the controller pushes to
  close an error. Shorten it if recovery from a water change is too sluggish;
  lengthen it if the heater output looks jumpy.
- **`full_scale_lux`** (default 3000) — set near the lux your sensor reads
  with the tank lights on at full.
- **`min_temperature` / `max_temperature`** — hard cutouts, not targets.

Press `Reset Learning` after anything that changes the tank's physics — new
heater, big volume change, moving the tank to another room.

## Notes on the TDS reading

**Read `TDS 1h Mean`, not `TDS`.** A single sample from this probe is honest
about nothing. Over a day of live data the spread *within one hour* had a
median of 39 ppm and a maximum of 171 ppm — bigger than any dose you would
ever make, which means two readings minutes apart can differ by more than a
water change does. This project spent real effort explaining a 47 ppm
"overnight rise" that was noise.

So `TDS 1h Mean` is a 120-sample sliding window at 30 s, republished every
minute, computed **on the device** so the panel, the web page and Home
Assistant all show the same number with no broker involved. `TDS` itself is
still published, and still worth plotting underneath the mean: seeing the
noise band is what stops the next spike reading as an event. `Electrical
Conductivity` follows the mean, since it is the same measurement × 2 and the
two disagreeing by 30 µS/cm would look like a fault.

Underneath that: the raw value is a median over 20 ADC samples, giving a new
voltage every 10 s, and it is temperature-compensated to 77 °F using the
DS18B20. The ppm curve is the DFRobot Gravity polynomial (the Keyestudio
board is a clone of it); µS/cm is derived as `ppm × 2`, not measured
independently.

The probe ships uncalibrated — see [Calibration](#calibration). It is also
not rated for permanent submersion, and biofilm reads as dissolved solids, so
pull and clean it periodically.

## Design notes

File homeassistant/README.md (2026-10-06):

# Home Assistant

## Aquarium dashboard

Live at **Settings → Dashboards → Aquarium**, or `/aquarium-tank`.
`aquarium-dashboard.json` is the config, kept here for version control.

Three views:

| View | Purpose |
|---|---|
| **Tank** | Live state — temperature, controller, water quality, health |
| **Manual tests** | Type test-kit results, press one button to log them |
| **Trends** | History: is the swing actually falling? |

### No probe cross-check any more

There used to be one here: the ESP32's DS18B20 was compared against a Seneye
Reef/Pond monitor, on the principle that two sensors in the same water should
agree. That monitor was returned on 2026-09-04 after its pH proved ~0.45 LOW
against an API liquid test — it had this project chasing a CO2 crisis and then
a KH crash, neither of which was real.

**So there is no second sensor now, and the gap is worth stating plainly:**
the controller drives the heater from the DS18B20 alone. If that probe reads
low, the controller will happily cook the tank while reporting the target, and
nothing in Home Assistant will notice. Check it against a reference
thermometer occasionally, by hand.

The lesson generalises past this one device. A continuous reading that cannot
be calibrated is not more trustworthy than an intermittent one that can — it
is less, because it is wrong more often and more confidently. That is why pH
is moving to a DFRobot glass electrode on the controller: it can be stood in
a buffer of known pH and proven right.

### The TDS number is an hourly mean, and the mean is computed on the device

The analog TDS probe is honest about the trend and useless about any single
sample. Measured over a day of live data, the spread WITHIN one hour was a
median of 39 ppm and as much as 171 ppm — larger than any dose you would ever
make. That is what had this project explaining a "47 ppm overnight rise" that
was noise.

So the dashboard reads `sensor.tank_monitor_tds_1h_mean`. **That sensor is
computed on the ESP32, not here** — a 120-sample sliding window at 30 s,
republished every minute, defined in `packages/sensors.yaml`.

It was briefly an HA `statistics` helper instead, which was the wrong place.
A correction that only exists in Home Assistant is a correction the tank does
not have: the remote panel over ESP-NOW and the controller's own web page
would still have been showing the raw jittering value, and would have
disagreed with this dashboard by 15–40 ppm at any given moment. The same
argument applies to every calibration — see the note below.

The raw probe is still plotted on the Trends view underneath the mean,
deliberately: seeing the noise band around the mean is what stops the next
spike being read as an event.

### Calibration lives on the device, not here

Every probe correction — TDS K factor, pH two-point, temperature offset — is
a `restore_value` global on the ESP32, applied inside the sensor lambda
before anything is published. Home Assistant receives values that are already
correct; it is a consumer, not the correction.

The entities are exposed to HA for convenience, but the same controls exist
on the device's own web page at its IP address, which is what you use when
the broker is down or when you are standing at a sink with a wet probe. See
the root `README.md` for the procedure.

### Manual entry

Uses the existing `input_number.aquarium_*` helpers and
`script.aquarium_log_manual_test` rather than duplicating them. GH and KH
have no hobby-grade probe, so they stay test-kit values — the Tank view's
target table reads them from the `*_log` sensors so they sit alongside the
measured parameters.

### Rebuilding

`aquarium-dashboard.json` is the source of truth here; the dashboard was
created from it via the HA config API, not hand-edited in the UI. If you
edit it in the UI, export it back to this file.

## 75-gal light — Chihiros WRGB II Pro 120

**The tank's own board owns the light.** Since 2026-09-29 the all-in-one
controller (`tank-monitor-75-gallon`, `boards/allinone-freenove.yaml`) holds a
BLE link to the lamp and pushes the selected phase itself
(`packages/light_wrgb2.yaml`). Home Assistant only shows and sets it, exactly as
it does for the heaters; nothing in HA re-pushes a schedule. The old
`aquarium-light-bridge` ESP32, `input_select.aquarium_75_light_phase` and
`automation.aquarium_75_apply_light_phase` are retired and were deleted from HA
on 2026-10-06.

Lives on the **`dashboard-modern` → Aquarium** view (`/dashboard-modern/aquarium`),
in the 75-gal block, gated on `input_select.aquarium_tank` = `75 Gal` like every
other section there. This is *not* on the `aquarium-tank` dashboard that
`aquarium-dashboard.json` tracks.

| Entity (prefix `tank_monitor_75_gallon_`) | What it is |
|---|---|
| `select…light_phase` | The phase: Off (cycling), Phase 1–4. Changing it pushes at once |
| `text…light_on_time` / `text…light_off_time` | Start and end of the photoperiod (HH:MM) for the selected phase |
| `number…light_ramp` | Dawn/dusk ramp, minutes |
| `number…light_white` / `_red` / `_green` / `_blue` | Plateau brightness, % |
| `number…light_full_brightness_hours` | >0 = this phase follows the sun (below); 0 = fixed times |
| `button…push_light_phase_now` | Re-send the selected phase |
| `button…release_light_for_app_30_min` | Hands the lamp to the Chihiros app for 30 min, then takes it back and re-pushes |
| `button…reset_light_phase_to_defaults` | Restores the selected phase to the table below |
| `binary_sensor…light_linked` | The BLE link to the lamp is up |
| `binary_sensor…light_not_responding` | Three re-pushes did not make the lamp match the schedule |
| `sensor…light_expected` | What the lamp should be doing now: lit / ramping / dark / off phase |
| `sensor…light_link_drops`, `…light_link_uptime`, `…light_link_last_drop` | Link health and the radio's reason for the last drop |

The controls edit **the selected phase** and are stored in the board's flash,
so tuning never needs a reflash; pick another phase and they show its values.

**Follow the sun (Phases 3–4).** With Full Brightness Hours > 0 the board
computes the window from today's sunrise and sunset at the tank (south-central
Pennsylvania, from the board's own clock — no HA needed): lights span sunrise
to sunset, the plateau is capped at that many hours, and the rest of the day
becomes the dawn and dusk ramp (15–150 min; on a long summer day the window is
trimmed symmetrically around solar noon). It is recomputed after midnight and
pushed while the lamp is dark. On Time / Off Time / Ramp then show the
computed values and refuse edits. Phases 1–2 keep fixed hours.

Defaults (`light_seed_defaults` / `light_seed_sun` in
`packages/light_wrgb2.yaml` — what a fresh board and "Reset" write; the live
values are whatever has been tuned since):

| Phase | Window | Ramp | W / R / G / B | Follows the sun |
|---|---|---|---|---|
| Off (cycling) | — | — | 0 / 0 / 0 / 0 (manual mode, dark) | no |
| 1 — Plants in | 09:00–16:00 | 45 | 45 / 36 / 20 / 14 | no |
| 2 — Shrimp | 09:00–16:00 | 45 | 55 / 45 / 28 / 20 | no |
| 3 — Fish | sunrise–sunset (fallback 09:00–16:30) | computed (fallback 45) | 60 / 50 / 32 / 24 | 7 h plateau |
| 4 — Mature | sunrise–sunset (fallback 09:00–16:30) | computed (fallback 45) | 70 / 60 / 38 / 30 | 7.5 h plateau |

Ratios are deliberate: white is the only dimming lever, and red/green/blue
track it at roughly 0.8 / 0.45 / 0.3. Chihiros' own default is blue at 0.8 of
white, which is most of why a new Pro fixture grows algae. Phase 2 (an
estimated 40–50 µmol/m²/s at the substrate) is the ceiling until CO2 runs;
Phases 3–4 are the CO2 ladder. See the DEFAULTS comment in
`packages/light_wrgb2.yaml` for the PAR each phase is sized to.

**The schedule still runs on the lamp.** A lit phase is pushed as an
auto-mode schedule (clear slots → schedule → auto → clock, the app's own
sequence — chihiros-esphome `ca8fc35`); the lamp then runs it off its RTC, so
the board or HA going down does not darken the tank. "Off (cycling)" is manual
mode at 0, which darkens it at once and does not relight itself. The board
re-pushes at 03:00 daily to resync the lamp's drifting clock, and on every
reconnect.

**The board checks the lamp.** `tank_lux` is lamp-only lux (daylight is
removed by its near-infrared signature on the AS7341). During a plateau the
board learns what "lit" reads; lit-when-it-should-be-dark or the reverse for
5 minutes triggers a re-push, at most one per 15 minutes, and after three that
do not take it raises Light Not Responding instead of hammering the radio.

### 75-gal CO2

Rebuilt in HA on 2026-10-06 to follow the light the board is actually
running, including the daily follow-the-sun times. The gas window is three
template sensors over the board's Light On Time / Off Time / Ramp; tune the
offsets in their `input_number` helpers, never in the automations:

| Helper | Value |
|---|---|
| `sensor.aquarium_75_co2_start` | light on + ramp − `input_number.aquarium_75_co2_lead` (90 min) |
| `sensor.aquarium_75_co2_stop` | light off − ramp − `input_number.aquarium_75_co2_stop_before_dusk` (90 min) |
| `sensor.aquarium_75_bubbler_start` | CO2 stop + `input_number.aquarium_75_bubbler_gap_after_co2` (180 min) |

All three go unknown when the board is offline, and an unknown time never
fires — gas does not start on a guess.

- **`automation.aquarium_75_co2_schedule`** — `switch.75g_co2` on at the start,
  off at the stop, again one hour after the stop (failsafe), and at **17:00
  absolute** (backstop that cannot be defeated by a blank sensor). The start is
  refused — with a notification — unless the light phase is not Off and the
  probe pH (`sensor.tank_monitor_75_gallon_water_ph`) is reporting and above the
  floor + 0.2.
- **`automation.aquarium_75_bubbler_schedule`** — `switch.75g_bubbler` off at the
  CO2 start, on at the bubbler start, and on at **22:00 absolute** as a
  backstop; every turn-on also forces CO2 off (gas yields to aeration, never
  the reverse).
- **`automation.aquarium_75_co2_ph_floor_cutoff`** — always enabled. Probe pH
  below `input_number.aquarium_75_ph_floor` (6.5) for 2 minutes while
  `switch.75g_co2` is on → gas off, bubbler on, persistent notification. It only
  ever turns gas off; the next scheduled start re-checks the floor.

The schedule and bubbler automations are **intentionally off** until the
November CO2 readiness gate; enable them together. Until then the airstone runs
around the clock. The old `input_datetime.aquarium_75_co2_on` / `_off` /
`_bubbler_on` fixed times were deleted.

The 75's manual pH helper (`input_number.aquarium_75_ph_manual`) is no longer
published to `tank-monitor-75g/chem/ph`: the 75 gal panel's pH now comes from
the controller's calibrated probe over BLE (v3 frame field 17).

> **`aquarium-dashboard.json` in this folder is stale.** It predates the two-tank
> restructure entirely — 4 nano-only sections, no visibility conditions, no tank
> selector header — while the live `aquarium-tank` dashboard has 7 sections, 6
> badges and the selector. Re-export before trusting this file again.

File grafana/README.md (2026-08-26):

# Grafana

Dashboard for the tank, querying InfluxDB 3 directly.

## 1. Add the datasource

In Grafana: **Connections → Add new connection → InfluxDB**.

| Field | Value |
|---|---|
| Query language | **SQL** |
| URL | `http://<home-assistant-ip>:8181` |
| Database | `homeassistant` |
| Token | your InfluxDB 3 API token |

Use the Home Assistant host's **IP address**, not `32b8266a-influxdb3` — that
hostname only resolves inside HA's container network, and Grafana is on
another box. Port 8181 is published on the HA host.

**Plain `http`, not `https`.** The App's config says `ssl: true`, but its
certificate files don't exist, so it serves plaintext. Pointing TLS at it
fails with `WRONG_VERSION_NUMBER`.

SQL, not InfluxQL or Flux: InfluxDB 3 is natively SQL, and Flux is not
supported at all on v3.

## 2. Import the dashboard

**Dashboards → New → Import → Upload JSON file** →
`tank-monitor-dashboard.json`, then pick the InfluxDB datasource when
prompted.

## How the data is shaped

The Home Assistant InfluxDB integration writes one **table per unit of
measurement**, not per entity:

| Table | Holds |
|---|---|
| `°F` | every Fahrenheit sensor in your house |
| `ppm` | TDS |
| `μS/cm` | conductivity |
| `%` | heater duty, fan duty, model confidence |
| `lx` | light level |

Each row carries `entity_id`, `domain`, `friendly_name`, and `value`. So every
query filters by `entity_id`, e.g.:

```sql
SELECT time, value FROM "°F"
WHERE entity_id IN ('tank_monitor_water_temperature', 'tank_monitor_water_temperature_f')
  AND $__timeFilter(time)
ORDER BY time
```

Note `entity_id` here is the **object id** — `tank_monitor_tds`, not
`sensor.tank_monitor_tds`.

## The panel that matters

**Temperature Swing (1h)** is the one to watch. It's peak-to-peak movement
over a rolling hour, computed on the ESP32. Starting around 3 °F and falling
toward 0.3 °F is the whole point of the build — the other panels explain
*why* it moved, but this one says whether it worked.

Give it a day before judging: the thermal model needs roughly that long to
train, which `Model Confidence` tracks.

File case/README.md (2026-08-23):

# Enclosure

Purpose-built for the **LAFVIN ESP32-C6 1.47" LCD** board, because nothing
off the shelf fits it.

The Waveshare-outline cases and the generic MakerWorld ESP32-C6 enclosure
both fail: they assume a board with the LCD centred and USB on a long edge.
This board is a stick — USB-C, BOOT and RESET are all crammed onto one short
end, with the glass filling the far two-thirds.

## Print this first: the fit gauge

`fit-gauge.stl` — six pockets, **21.0 to 23.5 mm in 0.5 mm steps**, each
stamped with its size. About five minutes, no supports.

Slide the board into each. The one that grips lightly without needing force
is your real board width. Put that number in `pcb_w` at the top of
`tank-monitor-case.scad` and re-render — the case is then correct by
measurement instead of by estimate.

This exists because the first coupon came out too loose. The board
dimensions here were scaled off photographs, and no amount of re-measuring
the same photographs fixes that. The gauge answers it directly.

## Then the coupon

`tank-monitor-fittest.stl` — a 10 mm slice through the **USB end**. Print it
after setting `pcb_w` from the gauge. It checks the two things the gauge
can't: that a USB-C plug reaches the port through the slot, and that the
walls clear BOOT and RESET.

Slide it onto the USB end, not the far end — the port cutout is in its end
wall.

## Then

| File | Notes |
|---|---|
| `tank-monitor-tray.stl` | print open-side up, no supports |
| `tank-monitor-lid.stl` | print face down, no supports |

**PETG, not PLA.** This sits above a warm, humid tank and PLA creeps.

0.2 mm layers, 3 perimeters, 20% infill. No supports needed on either part —
that's what the geometry was arranged for.

## Design choices that absorb the ±1 mm

- **USB-C is a full-width slot**, not a shaped port cutout. There is no
  alignment to get wrong.
- **The LCD window is cut 1 mm inside the glass** on every side, so the
  bezel laps over the edge and hides any positional error.
- **No BOOT/RESET holes.** Their positions are the least certain thing on
  the board, and once OTA works you never press them. If you need them,
  the lid pulls off.
- **0.4 mm clearance per side** around the PCB.

## Cable exit

The GPIO headers run down **both long edges** of this board, so wires leave
from both sides — not off the end. There's a 26 × 5 mm slot on each long
side, positioned over the header rows. Every stock case assumes USB and
nothing else, which is the other reason none of them work here.

## Changing dimensions

Everything is parametric. Edit the `BOARD` block at the top of
`tank-monitor-case.scad`, then:

```sh
openscad -o tank-monitor-tray.stl -D 'part="tray"' tank-monitor-case.scad
openscad -o tank-monitor-lid.stl  -D 'part="lid"'  tank-monitor-case.scad
```

`part` accepts `tray`, `lid`, `fittest`, or `all` (everything laid out on
one plate).

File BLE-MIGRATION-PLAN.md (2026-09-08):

# Panel and link migration plan

**Rewritten 2026-09-04** after the phase 1 coexistence test failed and a
Waveshare ESP32-S3 1.75" round AMOLED was ordered to replace the CYD. The
earlier version of this plan assumed the CYD would carry two transports at
once. It cannot, and it no longer needs to.

---

## 1. The one rule everything follows

**No device ever runs three radios.**

That is the whole lesson of phase 1. WiFi + ESP-NOW + BLE together on the CYD
killed the ESP-NOW link and then the web server. Every arrangement below keeps
each device to two.

| Device | Radios | Ever three? |
|---|---|---|
| C6 controller | WiFi + ESP-NOW | no |
| CYD panel (today) | WiFi + ESP-NOW | no |
| AMOLED panel (phase A) | WiFi + ESP-NOW | no |
| AMOLED panel (phase B) | WiFi + BLE | no |
| S3 controller (phase B) | WiFi + BLE | no |

The awkward transitional state is gone because **the new panel is a new
device**. It does not have to become BLE on the same day the controller does.

---

## 2. Phases

### Phase A — AMOLED panel on ESP-NOW — **DONE, and now ended (2026-09-08)**

The new panel joined as a second display speaking the transport that already
worked: new board file, new round UI, `packages/remote_display.yaml`
unchanged, CYD untouched. It did its job — the round UI was built and
debugged against live data while no S3 controller existed.

It is over. `tank-monitor-amoled-remote.yaml` no longer loads
`remote_display.yaml` and **cannot be pointed at the C6**. The panel pairs
with the S3 and nothing else.

### Phase B — panel switches to BLE — **BUILT, not yet deployed**

Done:

- `packages/ble_link.yaml` — controller side. BLE server, one telemetry
  characteristic (notify, 5 s) and one command characteristic.
- `packages/ble_link_panel.yaml` — panel side. `ble_client`, notify
  subscription, checked parser, the same ids the board files already read.
- Payload is at **v2**: v1 omitted the controller's hourly TDS mean, so the
  panel would have shown the raw value while the CYD showed the mean. v1
  shipped but nothing ever consumed it, so there was no debt to carry.
- The panel's `HEATING 42%` became `HEATING` / `COOLING` / `IDLE`. They are
  relays; there is no throughput to throttle.

Still required before it works:

1. **The S3's BLE MAC.** `ble_client` addresses peers only by MAC — no name
   or service lookup. It is in the S3's boot log as `ESP-IDF BLE MAC
   address:`, and it is *not* the WiFi MAC. Set `s3_ble_mac` in the wrapper;
   the shipped value is intentionally invalid so the build stops until you do.
2. **The S3 has to be running.** It is the only board that speaks BLE. As of
   2026-09-08 its 54 entities are registered in HA and all unavailable.
3. **MTU is verified at runtime, not assumed.** The payload is ~115 bytes
   against BLE's 23-byte default. The parser counts fields and checks the
   version; a short read publishes nothing and logs `bad payload: N of 15
   fields -- MTU too small?`. If that appears in the panel log, MTU
   negotiation is the cause.

Known gap: **the round UI is read-only.** It has no setpoint stepper and no
learning switch, so nothing on the panel writes to the command
characteristic. The CYD can do both. That gap has to close before the CYD
retires, or retiring it loses function.

Still open from the original Phase B: the learned thermal model carrying
across via `tank-seed/<device>/model`, and C6 + CYD retiring together.

---

## 3. The round UI is a redesign, not a port

466 × 466 on a **circular** face. The CYD layout is a rectangular grid — a
header bar with radio icons at its ends, cards left and right, nav buttons
along the bottom. **On a circle every one of those corners is physically
absent.** None of it survives.

That constraint pushes the design where it should have gone anyway:

- ~44.5 mm across at 466 px is a **0.095 mm pitch**, roughly twice as fine
  as the CYD
- A centred temperature at ~45% of the diameter is about **20 mm tall**,
  against 11 mm on the C6 and ~8 mm on the CYD. **Smaller panel, bigger
  number**, because a round face has no room for furniture
- AMOLED contrast beats the CYD's TN panel at a glance and off-axis, which
  matters as much as size for reading across a room
- The arc gauge already built for the CYD home page — temperature arc,
  value in the centre, colour through the band — was always wanting to be
  round. That concept ports; its coordinates do not

**Build it with proportional positioning, not absolute pixels.** The current
layout is hard-coded to 320×240 and that is why this is a rewrite rather than
a resize. Doing it again the same way just moves the debt.

---

## 4. On arrival — verify before designing

1. **PSRAM.** The preset carries `requires={"psram"}`; the framebuffer is
   466×466×2 = **424 KB** and cannot live in internal RAM. Confirm the board
   is the S3**R8** variant.
2. **Touch controller.** Probably FT3168 or CST816, but that is a guess, and
   guesses have cost real time in this project. Read it off the board or its
   docs before writing config.
3. **Round-safe bounds.** Nothing drawn outside the inscribed circle. Corner
   coordinates that compile fine are simply invisible.

Preset facts already confirmed from ESPHome:
`WAVESHARE-ESP32-S3-TOUCH-AMOLED-1.75`, CO5300 controller, 466×466, 16-bit,
`offset_width: 6`, `cs_pin: 12`, `reset_pin: 39`.

---

## 5. Phase 1's result, and what it still means

Recorded so it is not re-learned: **WiFi + ESP-NOW + BLE on the CYD fails.**
The panel lost ESP-NOW, then stopped answering HTTP entirely, at
1100ms/100ms passive scanning — already the gentlest useful setting.

A follow-up test (commit `5e02610`) disables the ESP-NOW radio to isolate
whether BLE or the ESP-NOW pairing was at fault.

**That test is now informative rather than blocking.** Under this plan no
device ever runs BLE and ESP-NOW together, so its answer no longer gates
anything. It is still worth knowing — a clean WiFi + BLE result on 2016
silicon makes phase B near-certain on the S3 — but the CYD can be reverted to
its working ESP-NOW build at any time without holding the plan up.

---

## 6. Still open

- Whether the S3 controller is the XIAO ESP32-S3 or the WROOM-32. Both
  measured and both fit; the XIAO has far more headroom, the WROOM-32 more
  GPIO and is already in hand.
- Whether to add an ADS1115 for pH, and a small OLED so the controller is
  not blind. Both should be decided **before** the controller board file is
  written rather than bolted on after.

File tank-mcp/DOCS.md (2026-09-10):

# Tank MCP

An MCP server for the aquarium, running as a Home Assistant App. It gives an
AI assistant a set of tools for the tank specifically -- read the controller
type in a test-kit result, keep a record of fish and shrimp
that have died, and say any of it out loud on an Echo.

It is not a general Home Assistant bridge. Every tool answers a tank question,
and answers it with a verdict attached: not "pH 7.33" but "pH 7.33, in range".

## Install

1. **Settings -> Apps -> Store -> ⋮ -> Repositories**, add
   `https://github.com/JoshuaSeidel/tank-monitor`.
2. Install **Tank MCP** from the store and start it.
3. Open the log. On first start it mints an API token and prints it:

   ```
   Tank MCP listening on http://0.0.0.0:8099/mcp
   API token: 3Qv…
   ```

   Copy that into your MCP client. To set your own instead, put it in the
   app's `api_token` option and restart.

The app talks to Home Assistant through the Supervisor proxy, so there is no
long-lived access token to create. It picks up the Mosquitto broker the same
way.

**Port.** The container listens on 8099, which is also what the ha-mcp App
uses. If Supervisor refuses to start it with *port 8099 is already in use*,
remap the host side under the app's Network settings — 8091 works. The
container port stays 8099; only the host port moves.

## Options

| Option | Default | What it does |
|---|---|---|
| `api_token` | *(generated)* | Bearer token MCP clients must send. Left empty, one is generated into `/data/api_token` and logged. |
| `device` | `tank_monitor` | Which controller the tools read and command — `tank_monitor` or `tank_monitor_v2`. |
| `default_echo` | `media_player.office` | Echo used by `announce` when no target is given. |
| `publish_livestock_to_mqtt` | `true` | Mirror the livestock ledger into Home Assistant as sensors. |
| `log_level` | `info` | |

## Connecting a client

The endpoint is streamable HTTP at `http://<home-assistant-ip>:<host-port>/mcp`,
with `Authorization: Bearer <api_token>`.

Claude Code:

```bash
claude mcp add --transport http tank \
  http://192.168.6.4:8091/mcp \
  --header "Authorization: Bearer <api_token>"
```

`GET /health` is unauthenticated and returns `ok`, for an uptime check.

## Tools

**Reading**

| Tool | Answers |
|---|---|
| `tank_report` | "How is the tank?" — everything, plus a ranked list of what is wrong. Start here. |
| `tank_status` | Temperature against setpoint, heater and fan duty, TDS, and controller problems. |
| `water_chemistry` | Every chemistry value with a verdict; GH/KH in both degrees and ppm. |
| `ph_status` | Current pH and **where it came from** — `probe`, `test kit` or `unavailable`. |
| `metric_history` | Min/max/mean of one metric over N hours. |
| `water_test_history` | Past manual tests recorded through this app. |

**Writing**

| Tool | Does |
|---|---|
| `log_water_test` | Writes the `input_number.aquarium_*` helpers, runs the existing log script, keeps its own copy. Accepts GH/KH as ppm *or* degrees. |
| `set_target_temperature` | Moves the setpoint. Refused outside 68–82 °F. |

**Livestock**

| Tool | Does |
|---|---|
| `add_livestock` | Records stock going in. |
| `log_loss` | Records a death, with a cause and a date. |
| `livestock_inventory` | What is alive, per species. |
| `loss_history` | Losses over N days, per species, with a per-week rate. |
| `stocking_history` | Every stocking event. |
| `delete_loss` | Undoes a mistaken entry. |

Species names are folded onto a canonical key, so "kuhlis", "Kuhli Loaches"
and "kuhli loach" all land on the same species rather than three.

**Alexa**

| Tool | Does |
|---|---|
| `announce` | Says arbitrary text on an Echo. |
| `speak_tank_report` | Says the current tank status. |
| `speak_livestock_report` | Says the inventory and recent losses. |
| `list_echo_speakers` | Lists usable targets. |

## Alexa

Two directions, and they work differently.

**Alexa tells you** — the `announce` and `speak_*` tools push through
`notify.alexa_media`, so an assistant can speak on any Echo on demand. Nothing
to set up beyond Alexa Media Player, which is already installed.

**You ask Alexa** — Alexa cannot call MCP, so the ask path is pure Home
Assistant. `script.aquarium_speak_status` builds the same spoken report from
Home Assistant state and announces it. To wire it to a phrase:

1. **Settings -> Home Assistant Cloud -> Alexa** and expose
   *Aquarium: speak status*. It appears to Alexa as a scene.
2. In the Alexa app: **More -> Routines -> +**, "When you say" →
   `tank report`, "Add action" → Smart Home → *Aquarium: speak status*.

Then "Alexa, tank report" gets the tank spoken back. The livestock lines in
that report come from the sensors below, so they appear once this app has run
at least once.

Water temperature is separately worth exposing to Alexa directly: it is a
native temperature sensor, so "Alexa, what's the tank temperature?" works with
no routine at all.

## What it publishes back to Home Assistant

With MQTT available, the ledger appears as real entities under an *Aquarium
Livestock* device — so dashboards and the spoken report can use them without
going through MCP:

- `sensor.aquarium_livestock_total`
- `sensor.aquarium_livestock_losses_7d`
- `sensor.aquarium_livestock_losses_30d`
- `sensor.aquarium_livestock_last_loss`
- `sensor.aquarium_livestock_days_since_loss`

Each carries the full per-species breakdown as attributes. All retained, so
they survive a broker restart.

## Data

The ledger is SQLite at `/data/tank.db` inside the app, which means it
survives restarts and updates and is included in Home Assistant backups.
Manual test values are *also* written to the existing Home Assistant helpers,
so the dashboard, the logbook entry, and the ESP32's own chemistry panel all
stay in sync — this app adds a record, it does not replace theirs.

## Thresholds

The verdicts are not generic. They are set for this tank's stock — soft-water
tetras, scaleless kuhli loaches, blue-eyes, and Neocaridina shrimp:

- Cold floor 73.4 °F, matching the ESP32's blue band and the Home Assistant
  cold-floor alarm.
- On-target means within 0.5 °F of the setpoint.
- Total ammonia (API kit): anything above 0 is worth acting on, 0.5 ppm is high.
  These are TOTAL ammonia bands, not the free-NH3 ones a Seneye slide reported —
  they are an order of magnitude apart, so do not mix them up.
- pH 6.5–7.8.
- Nitrate good below 20 ppm, water change due above 40.
- GH and KH are read from the `input_number.aquarium_*_target_*` helpers
  rather than hard-coded, so moving the target moves the verdict.

They live in `tankmcp/entities.py`.

## Tests

`tests/smoke_test.py` runs the real server against a stand-in Home Assistant
and drives it through a real MCP client — auth, every tool, the unit
conversions, the alias folding, and the refusals:

```bash
python -m venv .venv && .venv/bin/pip install -r requirements.txt
.venv/bin/python tests/smoke_test.py
```

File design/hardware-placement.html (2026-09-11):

# Placement — vertical Jager heaters

Plan view, back wall at top. A vertical heater reads as a circle here — you're looking down the cylinder. The spray bar discharges forward across the full width; water runs down the front glass, along the bottom, and returns to the intake at back-right. All three options keep every piece of hardware against the back wall. The difference is lateral position, and it decides whether your two probes are measuring the tank or measuring your mounting choices.

Option A

### Back corners

Your original plan — a heater in each back corner, probes on the front glass.

Heater R sits beside the intake. Its heat short-circuits into the canister and barely warms its own half.

Both heaters in the dead corners, outside the spray bar's discharge.

Halves aren't comparable — the gradient measures plumbing, not heating.

✓ Recommended

### Inboard mirrored, all back

Heaters vertical on the back wall, inboard of the corners, mirrored about the centre feed. Probes also on the back wall, mirrored, offset laterally from each heater.

Both heaters sit in the spray bar's discharge — heat leaves immediately instead of pooling.

Mirrored about centre, so the halves are genuinely comparable and the gradient measures heating.

Heater R is well clear of the intake, so it warms water instead of feeding the canister.

Probes sit ~4″ below the bar and lateral to each heater — never directly above one, where the plume rises.

Option C

### Inboard heaters, front probes

Same heater placement as B, but probes on the front glass where you can see and service them without reaching behind hardscape.

Heaters identical to B — same distribution, same symmetry.

Probes readable and serviceable without disturbing the scape.

Each probe is directly downstream of its heater. The bar pushes that warm lane forward onto it, so expect a slightly hotter reading than bulk.

Visible from the front — the one thing you said you wanted to avoid.

Heater (vertical — seen end-on)

Temp probe

Spray bar / intake

Centre brace

Flow

#### Why the probes move inboard rather than outboard

The obvious alternative — push each probe out toward its side wall — fails on the right, because that corner is the intake. A probe there reads water on its way out of the tank, which is the least representative sample available. Inboard keeps both probes in equivalent flow and preserves the mirror.

Vertical costs you almost nothing. Horizontal-and-low would have added convection assist through the water column, but a 528 gph canister through a full-width spray bar is doing far more mixing than natural convection ever would. What actually mattered — inboard of the dead corners, mirrored about centre, clear of the intake — all survives.

Two Jager limits to check against your tank: water must never drop below the minimum mark on the housing, and maximum immersion depth is 0.5 m / 19.7″. On a tank taller than about 20″ that means the heater body hangs in the upper water column rather than reaching the substrate — which suits this layout fine, since it puts the elements right in the spray bar's discharge.

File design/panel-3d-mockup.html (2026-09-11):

# Interior perspective — Option B, vertical heaters

Built to the actual arrangement: intake back-right, spray bar across the back fed from centre, vertical heaters inboard on the back wall, mirrored about the centre feed, probes mirrored inboard of each heater, top split by a centre brace with a fan over each half. One-point perspective interior; hardware hazed toward the water colour in proportion to depth, which is what sells the third dimension and costs nothing because every blend is precomputed against a known background.

Display Tank WI-FIBLEMQTT 06:42

Water temperature 74.1 °F Setpoint 74.0 · heating

Gradient · L−R+0.18 °F

pH7.18

TDS342 ppm

HEATER L HEATER R FANS OFF

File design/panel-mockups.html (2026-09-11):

# Tank Monitor — 4.3″ panel, three design directions

Waveshare ESP32-S3-Touch-LCD-4.3 · 800×480 · rendered 1:1. Physical face ≈ 94 × 56 mm. All three share one system: deep cool-black ground, a single elevation layer (inset top highlight + drop shadow — LVGL does both natively), wide-tracked uppercase micro-labels, and tight negative letter-spacing on the numerals. Heat is orange, cool is blue, and relays read ON/OFF, never a percentage.

## 1 · Orbit — radial gauge + bento

The arc isn't decoration: it shows where in the safe band you are, with the setpoint as a tick. Diverging blue→neutral→orange, so drift reads as direction before you parse the digits.

Display Tank WI-FIBLEMQTT 06:42

74.1°F

▲ Heating

Setpoint 74.0

Left · intake74.2 °F

Right · return74.0 °F

Gradient +0.18 °F

−1.0 cool Lwarm L +1.0

pH7.18

TDS342 ppm

HEATER L HEATER R FAN OFF

## 2 · Vessel — the tank itself

Data mapped to physical space. Heat glow sits where the heaters actually are, probe pins read out in place, and the intake is marked — so a gradient is something you see on the correct side rather than a signed number you decode.

Display Tank WI-FIBLEMQTT 06:42

Tank · front elevation

Water temperature 74.1 °F HEATING · SP 74.0

Gradient+0.18 °F

pH / TDS 7.18 · 342 ppm

HEATER L HEATER R FAN OFF

## 3 · Monolith — restraint

One number, sized so it reads from the far side of the room, and nothing competing with it. Everything else is one quiet row; the rest lives on swipe pages. Modern by subtraction — and the most legible at a glance, at 6am, from a doorway.

Display Tank WI-FIBLEMQTT 06:42

Water temperature

74.1°F

HEATING Setpoint 74.0 · +0.1 above

Left74.2 °F

Right74.0 °F

Gradient+0.18 °F

pH7.18

TDS342 ppm

HEATER L HEATER R FAN OFF

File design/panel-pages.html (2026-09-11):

# 4.3″ panel — three pages, swipe between

All rendered 1:1 at 800×480. Page dots bottom-right track position. Everything here maps to an ESPHome display: lambda primitive — the gauge ring is native filled_ring, the charts are native graph + legend, the tank is filled_triangle / horizontal_line with precomputed depth blends.

## Page 1 · Main

Radial band gauge as the anchor — position within the safe band, setpoint as a tick. Diverging blue→neutral→orange so drift reads as direction before you parse digits.

Display Tank WI-FIBLEMQTT 06:42

74.1°F

▲ Heating

Setpoint 74.0

Left half74.2 °F

Right half74.0 °F

Gradient+0.18 °F

pH7.18

TDS342 ppm

HEATER LHEATER R FANS OFF

## Page 2 · Vessel

Rimless glass, no plastic chrome. You look into the tank: back wall, floor with real area, hardware at true depth hazed toward the water colour. Heaters vertical and mirrored, probes mirrored inboard, intake back-right, spray bar just under the surface. Substrate is 2″ Stratum under a 1.5″ black sand cap, banked up at the back — the layers show in cross-section through the front glass.

Display Tank WI-FIBLEMQTT 06:42

Water temperature74.1 °F Setpoint 74.0 · heating

Gradient · L−R +0.18 °F

Heating vs idle +0.21 / +0.04 °F

HEATER LHEATER R FANS OFF

## Page 3 · Chemistry & trends

Native graph component. pH carries its safe band as a shaded reference — the 7.0 floor your danios and shrimp set. TDS shows raw against the hourly mean on one axis, never two, so the smoothing is visible rather than implied.

Display Tank WI-FIBLEMQTT 06:42

pH · 24 hours

7.18▲ 0.06 vs 24 h ago

pH

Target band

TDS · 24 hours

342 ppmhourly mean

Hourly mean

Raw

GH124 ppm

KH71 ppm

pH cal age18 days

Next test dueToday

HEATER LHEATER R FANS OFF

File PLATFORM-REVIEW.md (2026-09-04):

# Platform review — 2026-09-04

Written after four unit-mislabel bugs surfaced in a single day. None of them were
new; all four had existed for weeks, and each had survived a previous "fix" that
touched one representation of the value and left the others alone.

This document is the holistic pass. It is deliberately not a patch list.

---

## 1. The structural problem

**A single quantity is represented in up to eleven places, and nothing checks that
they agree.** GH is the worst case:

| # | Surface | What it holds |
|---|---|---|
| 1 | `input_number.aquarium_gh` | the value |
| 2 | `input_number.aquarium_gh_target_min` / `_max` | the target band |
| 3 | `sensor.aquarium_gh_log` | a template sensor with its own unit attribute |
| 4 | dashboard-modern → Aquarium, section 2 card 13 | verdict logic + unit label |
| 5 | dashboard-modern → Aquarium, section 6 card 4 | the saved-test summary |
| 6 | `/aquarium-tank` Tank view | targets table |
| 7 | `homeassistant/aquarium-dashboard.json` | a hand-maintained repo snapshot |
| 8 | `tank-mcp/tankmcp/entities.py` | `MANUAL` and `TARGETS` maps |
| 9 | `tank-mcp/tankmcp/readings.py` | verdict + unit conversion |
| 10 | `script.aquarium_log_manual_test` | the permanent logbook line |
| 11 | `packages/chemistry.yaml` + board files | MQTT mirror to the ESP32 panel |

Changing the unit in one place changes nothing anywhere else, and **no surface
declares its unit in a way another surface can read**. The unit lives in a display
attribute (invisible to templates), in prose, and in Python string keys.

That is why patching kept producing the next bug.

---

## 2. Findings

Severity is about **how wrong a decision it can cause**, not how ugly it is.

### 🔴 Live and wrong

**F1 — A dashboard card still instructs entering degrees.**
`dashboard-modern` → Aquarium, section 2 card 13 reads *"Enter them below in **dGH /
dKH**, not the ppm printed on test strips — divide the strip's ppm by 17.9"* and
renders `GH {{ gh }} dGH`. The helper is ppm. Following that card's instruction
today would enter a value ~18× too small into a ppm field. This card was missed by
every pass so far, including today's.

**F2 — The compiled temperature setpoint is 76.0 °F.**
`packages/base.yaml` `target_temp_f: "76.0"` → `packages/control.yaml`
`setpoint: ${target_temp_f}`. The live value is 74.0 and survives because the number
entity has `restore_value: true`. **A fresh flash, or any board whose NVS is cleared,
boots the tank at 76 °F** — 2 °F above where it should be, with shrimp in it.

**F3 — Two different cold floors.**
`tank-mcp` `TEMP_COLD_FLOOR_F = 73.4` vs the Home Assistant alarm's 73.0. The spoken
report says "below the cold floor for the loaches" at a temperature the alarm does
not consider cold.

### 🟠 Disagreeing, consequence bounded

**F4 — Four different pH upper bounds.**
`aquarium_ph_out_of_range` says 8.0 · `tank-mcp` `PH_MAX` says 7.8 · the targets card
says 7.5 · nothing reads a helper. The *lower* bounds (7.0 cutoff, 6.8 alarm) are
deliberate tiering and are fine; the upper bounds are drift.

**F5 — Only GH and KH have target helpers.**
Nitrate, nitrite, ammonia and pH bands are hard-coded in the MCP app, the automations
and the dashboard cards independently. There is no single place to change "what good
looks like" for four of the six chemistry values.

**F6 — `homeassistant/aquarium-dashboard.json` is a hand-maintained duplicate.**
It has been edited separately from the live dashboard twice today. It will drift
again; it is a snapshot pretending to be a source.

### 🟡 Known, accepted, or already tracked

**F7 — `tds_k_factor: "1.0"`.** The TDS probe has never been calibrated. Tracked on
the new Sensor verification card; the 342 ppm / 700 µS standard is on order.

**F8 — No second temperature probe.** Accepted deliberately after the Seneye was
returned. Recorded in `homeassistant/README.md` and the alarm's own description.

**F9 — `PPM_PER_DEGREE = 17.9` survives in `tank-mcp`.** Now used only to *derive*
a degrees figure for display, which is correct — but it is the constant that caused
the ×18 bug and deserves the comment it now has.

---

## 3. Target architecture

Three rules, in priority order.

### Rule 1 — The unit belongs in the identifier, not an attribute

`input_number.aquarium_kh_ppm`, not `input_number.aquarium_kh` with a `ppm` unit
attribute. A template that reads the wrong thing then *looks* wrong at every call
site, in every surface, without running anything.

This is the only change that makes the class of bug visible rather than latent.

### Rule 2 — One source of truth per quantity, read everywhere else

Every band gets a helper, and every consumer reads it. No hard-coded thresholds in
dashboard cards, MCP constants or automation triggers where a helper could be read.

The exception worth keeping: **deliberate tiering.** The CO2 cutoff at 7.0 and the
alarm at 6.8 are supposed to differ. Tiering should be expressed as an offset from
the helper, not as a second independent number.

### Rule 3 — Generated artifacts are generated, not hand-edited

`homeassistant/aquarium-dashboard.json` should be exported from the live dashboard by
a script, never edited directly. Otherwise it is a third copy of the truth.

---

## 4. Migration order

Sequenced so each step leaves the system working.

| Step | Change | Why this order |
|---|---|---|
| 1 | Fix **F1** and **F2** | Both can cause a wrong action today; neither depends on the rest |
| 2 | Add target helpers for pH, nitrate, nitrite, ammonia | Creates the sources of truth Rule 2 needs |
| 3 | Repoint every consumer at the helpers (cards, MCP, automations) | Removes the hard-coded copies |
| 4 | Rename GH/KH/TDS helpers to `_ppm` | The big one. Do it *after* step 3 so there are fewer consumers to update |
| 5 | Reconcile F3 and F4 to single values | Trivial once the helpers exist |
| 6 | Replace the dashboard JSON snapshot with an export script | Stops the duplicate re-forming |

**Step 4 is the rename that was started and stopped.** Nothing was written; the
consumer search is in the session log. It is deliberately sequenced last because
doing it first means renaming entities that a dozen hard-coded card templates still
reference.

---

## 5. What this review does not cover

- The ESPHome control loop and learning model, reviewed separately on 2026-09-03
- `tank-mcp`'s livestock ledger
- Grafana dashboards in `grafana/`
- Whether the KH *target* should be 54–72 ppm or 90–125 ppm. That is a fishkeeping
  decision, not an architecture one, and it is still open.

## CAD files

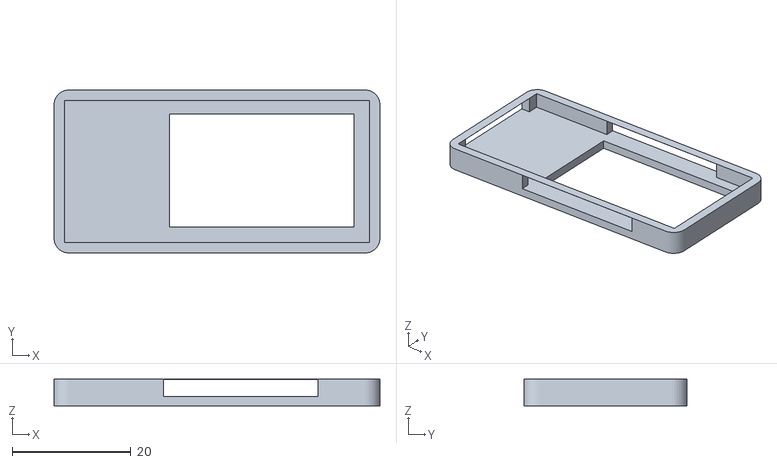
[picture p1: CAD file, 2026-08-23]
case/tank-monitor-lid.stl
54.8 x 27.4 x 4.50

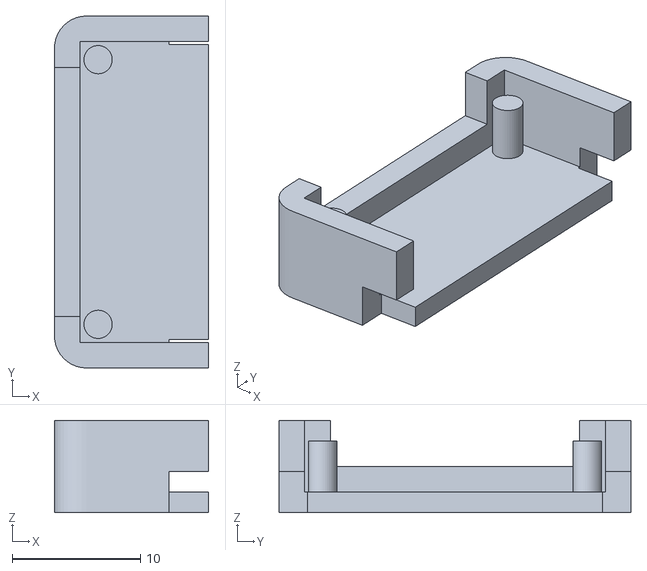
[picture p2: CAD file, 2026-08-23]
case/tank-monitor-fittest.stl
12.0 x 27.4 x 7.20

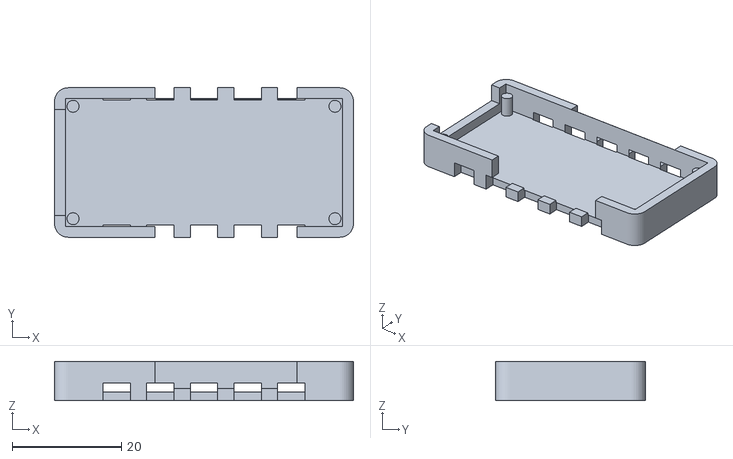
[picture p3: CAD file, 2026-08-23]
case/tank-monitor-tray.stl
54.8 x 27.4 x 7.20

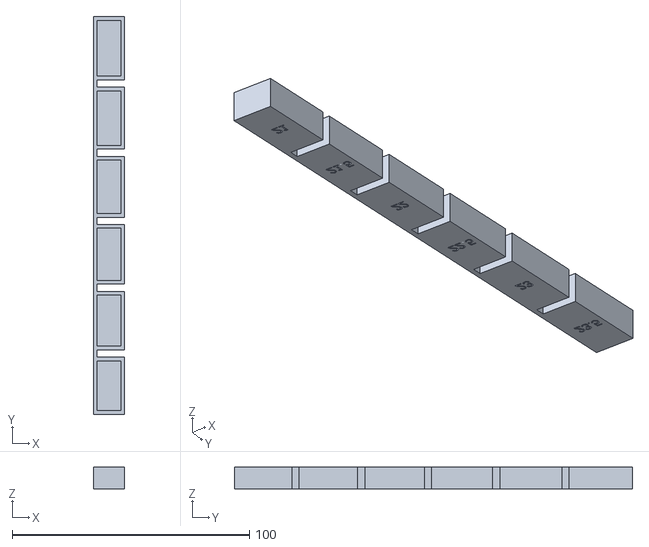
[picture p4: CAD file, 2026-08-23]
case/fit-gauge.stl
13.2 x 167.7 x 9.20

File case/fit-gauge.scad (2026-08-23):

// Fit gauge -- find the real board width and thickness by trying them.
//
// Six pockets, 21.0 to 23.5mm in 0.5mm steps, each stamped with its size.
// Slide the board into each. The one that grips lightly without force is
// your number; put it in tank-monitor-case.scad as pcb_w and the design
// is correct by measurement rather than by estimate.
//
// Prints in about five minutes. No supports.

widths = [21.0, 21.5, 22.0, 22.5, 23.0, 23.5];

slot_l   = 10;    // how far the board slides in
depth    = 8;     // pocket depth -- deeper than any plausible board stack
wall     = 1.6;
base     = 1.2;
gap      = 3;     // between pockets
label_h  = 0.6;

$fn = 24;

module pocket(w, label) {
  outer_w = w + 2 * wall;
  difference() {
    cube([slot_l + wall, outer_w, base + depth]);
    // the pocket itself, open at +X so the board slides in
    translate([-0.01, wall, base])
      cube([slot_l + 0.02, w, depth + 0.01]);
    // size stamped into the base, readable from below
    translate([slot_l / 2 + wall / 2, outer_w / 2, -0.01])
      linear_extrude(label_h + 0.01)
        text(label, size = 3.2, halign = "center", valign = "center");
  }
}

// Lay the pockets out and tie them together with a spine, so it prints and
// handles as one comb rather than six pieces to lose on the bench.
function y_at(i) = (i == 0) ? 0 : y_at(i - 1) + widths[i - 1] + 2 * wall + gap;

span = y_at(len(widths) - 1) + widths[len(widths) - 1] + 2 * wall;

for (i = [0 : len(widths) - 1])
  translate([0, y_at(i), 0]) pocket(widths[i], str(widths[i]));

// spine along the closed end
translate([-wall, 0, 0]) cube([wall, span, base + depth]);

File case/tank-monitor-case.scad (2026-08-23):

// Tank Monitor enclosure -- LAFVIN ESP32-C6 1.47" LCD board
//
// LAFVIN publishes no mechanical drawing and the Waveshare-outline cases
// do not fit this board, so these dimensions come from photographs and
// are good to roughly +/-1mm. The design is built to tolerate that:
//
//   * USB-C is a full-width slot, not a shaped port -- nothing to misalign
//   * the LCD window is cut inside the glass edge, so the bezel hides error
//   * BOOT/RESET get no holes at all (see note below)
//
// Before printing the whole thing, set part="fittest" and print that. It
// is a 10mm slice of the pocket and the USB end -- about 3 minutes -- and
// tells you whether pcb_l/pcb_w/depth are right.

part = "all";   // "all" | "tray" | "lid" | "fittest"

/* [BOARD -- replace with caliper readings if you get them] */
// First coupon (pcb_w 23.0, pocket 23.8) was loose. Down 0.5mm.
// fit-gauge.stl gives the definitive number if this is still off.
pcb_l = 50.0;     // long dimension, USB end to far end
pcb_w = 22.6;     // short dimension
pcb_t = 1.6;      // bare PCB thickness

back_h  = 4.0;    // tallest component on the BACK
front_h = 2.5;    // glass + ribbon height above the PCB front

// The glass runs from the far end back toward the USB end and is very
// nearly the full board width.
lcd_l      = 33.0;   // glass length along pcb_l
lcd_w      = 21.0;   // glass width along pcb_w
lcd_gap    = 1.0;    // glass inset from the FAR end
lcd_off_w  = 1.0;    // glass inset from one long edge

/* [FIT] */
clearance = 0.4;    // per side around the PCB
wall      = 2.0;
floor_t   = 1.6;
bezel_t   = 1.6;
overlap   = 1.0;    // how far the bezel laps over the glass

/* [CABLE EXIT] */
// The GPIO headers run down BOTH long edges of this board, so wires leave
// from both sides -- not off the end. Slots on each long side, positioned
// over the header rows.
cable_w = 26.0;   // slot length, along pcb_l
cable_h = 5.0;

eps = 0.01;
$fn = 40;

// ---- derived ----------------------------------------------------------
in_l   = pcb_l + 2 * clearance;
in_w   = pcb_w + 2 * clearance;
out_l  = in_l + 2 * wall;
out_w  = in_w + 2 * wall;
tray_h = floor_t + back_h + pcb_t;
skirt  = front_h + 0.4;

module rrect(l, w, h, r = 2.5) {
  hull() for (x = [r, l - r], y = [r, w - r]) translate([x, y, 0]) cylinder(r = r, h = h);
}

// USB end is at x = 0. Full-width slot: no alignment to get wrong.
module usb_slot() {
  translate([-eps, wall + 2, floor_t + back_h + pcb_t - 3.6])
    cube([wall + 2 * eps, in_w - 4, 3.8]);
}

module cable_slot() {
  // Both long edges, centred on the header rows.
  for (y = [-eps, out_w - wall + eps])
    translate([(out_l - cable_w) / 2 + 4, y, tray_h - cable_h])
      cube([cable_w, wall + 2 * eps, cable_h + eps]);
}

module tray() {
  difference() {
    rrect(out_l, out_w, tray_h);
    translate([wall, wall, floor_t]) cube([in_l, in_w, tray_h]);
    usb_slot();
    cable_slot();
    // Vents -- this hangs above a warm, humid tank
    for (i = [-1, 1], j = [0 : 4])
      translate([out_l / 2 - 16 + j * 8,
                 out_w / 2 + i * (out_w / 2 - wall / 2), floor_t / 2])
        cube([5, 2.4, floor_t * 3], center = true);
  }
  // Posts that stop the board sliding, all below board level
  for (x = [wall + 1.4, out_l - wall - 1.4], y = [wall + 1.4, out_w - wall - 1.4])
    translate([x, y, floor_t]) cylinder(r = 1.1, h = back_h);
}

module lid() {
  // Window sits INSIDE the glass by `overlap` on every side, so a 1mm
  // error in the glass position is still covered by bezel.
  win_l = lcd_l - 2 * overlap;
  win_w = lcd_w - 2 * overlap;
  win_x = wall + clearance + (pcb_l - lcd_gap - lcd_l) + overlap;
  win_y = wall + clearance + lcd_off_w + overlap;

  difference() {
    union() {
      rrect(out_l, out_w, bezel_t);
      difference() {
        translate([0, 0, bezel_t]) rrect(out_l, out_w, skirt);
        translate([wall - 0.2, wall - 0.2, bezel_t - eps])
          cube([in_l + 0.4, in_w + 0.4, skirt + 2 * eps]);
      }
    }
    translate([win_x, win_y, -eps]) cube([win_l, win_w, bezel_t + 2 * eps]);
    // The USB slot continues through the skirt
    translate([-eps, wall + 2, bezel_t - eps]) cube([wall + 2 * eps, in_w - 4, skirt]);
    for (y = [-eps, out_w - wall + eps])
      translate([(out_l - cable_w) / 2 + 4, y, bezel_t - eps])
        cube([cable_w, wall + 2 * eps, skirt]);
  }
}

// A 10mm slice through the USB end. Print this first.
module fittest() {
  intersection() {
    tray();
    cube([12, out_w, tray_h]);
  }
}

if (part == "tray") tray();
else if (part == "lid") lid();
else if (part == "fittest") fittest();
else {
  tray();
  translate([0, out_w + 4, 0]) lid();
  translate([0, 2 * out_w + 8, 0]) fittest();
}

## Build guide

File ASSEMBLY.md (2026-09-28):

# Assembly

Four boards are covered here and they wire up differently:

- **[ESP32-C6 (`tank-monitor`)](#esp32-c6-tank-monitor)** — solder directly to
  the board's pads.
- **[CYD ESP32-2432S028R (`tank-monitor-v2`)](#cyd-esp32-2432s028r-tank-monitor-v2)** —
  display-only remote panel. No wiring at all.
- **[ESP32-WROOM-32 (`tank-monitor-w32`)](#esp32-wroom-32-tank-monitor-w32)** —
  headless controller. Same wiring as the C6 on different pins.
- **[ESP32-S3 mini (`tank-monitor-s3`)](#esp32-s3-mini-tank-monitor-s3)** —
  headless controller in 23 × 18 mm. Solder directly to the board.
- **[XIAO ESP32-S3, large tank (`tank-monitor-75-gallon`)](#xiao-esp32-s3-large-tank-tank-monitor-75-gallon)** —
  headless controller, two of everything. Sensors on an ADS1115, three relay
  channels, two 1-Wire buses. Needs a power rail, not a splice.

Build order matters on both: power bus first, sensors one at a time, relay
last. That way if something is wrong you know which step caused it.

# ESP32-C6 (`tank-monitor`)

**Nothing is plugged in — no USB, no mains — until step 8.**

## What you need

- 26–28 AWG stranded hookup wire (silicone jacket is easiest to work with)
- 4.7 kΩ resistor (1/4 W)
- Heat shrink, 2 mm and 3 mm
- Soldering iron ~625 °F (330 °C), thin rosin-core solder
- Multimeter

Everything solders directly to the ESP32-C6 board. No breakout, no perfboard.

## 1. Prep the board

Identify the pads by the silkscreen labels on the back: `3V3`, `GND`, and the
GPIO numbers you need — **1, 10, 18, 19, 20**.

Tin each pad: touch the iron to the pad, feed a small amount of solder, remove.
You want a shiny dome, not a blob. Two seconds per pad — the C6 is fine but
don't dwell.

## 2. Pre-tin every wire end

Every wire, both ends, including the sensor pigtails. Twist the strands, tin
them, then trim to ~3 mm. Untinned stranded wire fans out and bridges
neighbouring pads, which is the single most common way this build goes wrong.

**Slide heat shrink onto the wire before you solder it.** You will forget at
least once. Everyone does.

## 3. Splice the power wires

There is one `3V3` pad and one `GND` pad, but three sensors need power and
four wires need ground. You can't stack that many wires on a single pad and
get a joint that survives being moved.

So join them **off the board** and run a single pigtail to each pad.

**3V3 splice — three wires plus a pigtail:**

```
   DS18B20 red   ─┐
   TDS VCC       ─┼──[ twist + solder + heat shrink ]──── pigtail ──► 3V3 pad
   BH1750 VCC    ─┘
```

**GND splice — four wires plus a pigtail:**

```
   DS18B20 black ─┐
   TDS GND       ─┤
   BH1750 GND    ─┼──[ twist + solder + heat shrink ]──── pigtail ──► GND pad
   Relay IN− ×2  ─┘
```

For each splice: strip ~10 mm on every wire including the pigtail, twist all
the conductors together into one bundle, flow solder through until it wicks
right through, then cover the whole thing with 3 mm heat shrink. Slide the
shrink on first.

The two relay `IN−` terminals can share one wire — jumper between them at the
module and run a single lead back to the splice.

**Solder the two pigtails to the board first**, then check with a multimeter
that there is **no continuity between 3V3 and GND**. Find a short now, not
after everything else is attached.

## 4. Sensor power

Already done — it's in the splices from step 3. Just confirm each sensor is on
the right one:

| Sensor | 3V3 splice | GND splice |
|---|---|---|
| DS18B20 | red | black |
| TDS board | VCC | GND |
| BH1750 | VCC | GND |

**TDS goes to 3.3 V, never 5 V.** 5 V on its output will destroy GPIO1.

## 5. Signal wires

One at a time, board pad → sensor:

| Board pad | Goes to |
|---|---|
| GPIO18 | DS18B20 yellow (DQ) |
| GPIO1 | TDS `A` |
| GPIO19 | BH1750 `SDA` |
| GPIO20 | BH1750 `SCL` |

Leave BH1750 `ADDR` unconnected — floating is address 0x23, which is what the
config expects.

Shrink each joint as you go.

## 6. The 4.7 kΩ pull-up

Solder it between the **DQ line and 3V3**, at the *board* end of the run —
not out at the probe. Easiest way: include one resistor leg in the 3V3 splice
when you make it in step 3, and solder the other leg onto the GPIO18 wire
where it leaves the board.

Sleeve both legs with heat shrink. Bare resistor legs near a tank are a short
waiting to happen.

Without this resistor the DS18B20 reads nothing or garbage. Any value from
2.2 kΩ to 10 kΩ will do — 4.7 kΩ is convention, not a requirement.

If you don't have one yet, the README covers switching to the C6's internal
pull-up as a bench-test stopgap. It is not a permanent substitute.

## 7. Relay control pair

Two signal wires plus one ground, to the D-1584TL's **low-voltage terminals
only**:

| Board pad | D-1584TL |
|---|---|
| GPIO2 | Channel 1 `IN+` (heater) |
| GPIO3 | Channel 2 `IN+` (fan) |
| GND splice | `IN−`, both channels (jumpered together) |

Do not open the relay module or touch its mains side. It has its own cord.

**Route the TDS signal wire away from the relay's power cord.** High-impedance
analog next to a mains cable picks up 60 Hz hum, and you'll chase a noisy
reading that isn't a sensor fault.

## 8. Inspect before powering

1. Look at every joint under decent light, splices included. Shiny and concave is good; dull,
   cracked, or ball-shaped means reheat it.
2. Multimeter continuity, **3V3 to GND: must be open.**
3. Tug each wire gently. Anything that moves gets resoldered.

## 9. Power up in stages

1. USB-C only, nothing else connected to mains. The LCD should light.
2. `esphome logs tank-monitor-remote.yaml`. Look for the DS18B20 address and a
   BH1750 found at 0x23 in the I²C scan.
3. Check the TDS voltage reading with the probe **dry** — should sit near 0 V.
4. Only now plug in the relay module. Confirm the heater outlet clicks when
   `Heater Output` goes above 0%.
5. Wet the probes and confirm sensible readings before putting anything in
   the tank.

## 10. Before it goes near water

- Strain-relieve every wire where it leaves the board — a dab of hot glue or
  a zip tie to the case is enough. Vibration and cable weight break solder
  joints, not the wire.
- Mount the board **above** the water line. Condensation runs downhill.
- Put the whole thing on a GFCI outlet. This is an aquarium; the fish are the
  reason but you are the other reason.

# CYD ESP32-2432S028R (`tank-monitor-v2`)

**There is no wiring.** This board is display-only: it subscribes to the C6's
values over the network and draws them. No probe, no TDS meter, no light
sensor, no relays, no pull-up resistor — nothing lands on its connectors.

That is deliberate. This board spends nearly every GPIO on its own screen and
touch panel, so making it a controller meant repurposing the microSD bus,
hanging the light sensor off the pins the USB bridge uses to flash the chip,
and metering the speaker header to learn whether it reached a pin or an
amplifier. The C6 already has a probe bolted to the tank and a control loop
that has been running it for weeks. Splitting the roles removes the whole
class of problem.

## Setup

1. Flash it. The wrapper loads `packages/remote_display.yaml` in place of
   `control.yaml` and `sensors.yaml`.
2. Power it by USB anywhere on your Wi-Fi. It does not need to be near the
   tank — that is the point of a remote panel.
3. Confirm it works: temperature, TDS and light should populate within a few
   seconds, and the `Link Age` entity should read a few seconds rather than
   `no data`.

`Link Age` is the one to watch. The panel is only ever as current as its last
message, and a frozen screen showing plausible numbers is the failure worth
making visible.

## Controlling from the panel

The setpoint buttons and the Adaptive Learning switch publish commands to the
C6's MQTT topics; the C6 remains the authority and its state topic corrects
the panel a moment later. So the panel changes the tank, but it never holds an
opinion the controller doesn't share.

## The microSD slot

Free again, since nothing uses IO18/19/23 now. ESPHome has no SD component in
core, so using it needs an external component — worth doing for local logging
(the Home Assistant host has no UPS, and that is what corrupts InfluxDB), but
it is not part of this build.

## The ESP-NOW link

The panel gets its data straight from the controller over ESP-NOW — peer to
peer, no router and no MQTT broker. Since the broker runs on Home Assistant,
this is what lets the panel keep working with Home Assistant down.

Two things have to be true:

**`espnow_key` in `secrets.yaml`, identical on both boards.** Any string. A
missing value fails the build, which is deliberate — an unencrypted link would
work perfectly and silently accept a setpoint command from anyone in range.

**The router's 2.4 GHz channel must be pinned.** ESP-NOW shares one radio with
Wi-Fi and can only work on the channel the station is already associated on —
ESPHome enforces this by rejecting a `channel:` setting whenever the wifi
component is present. Both boards land on the AP's channel, so they can hear
each other. **If the AP is ever set back to "auto" and moves, the link stops
with no error on either board:** packets go out on a channel nobody is
listening to. `Link Age` on the panel is what makes that visible.

Home Assistant is unaffected. Every entity still publishes over MQTT exactly as
before — this is a second path for one consumer, not a replacement. Chemistry
still arrives by MQTT too, because it originates in Home Assistant; with HA
down it goes stale and the panel says so.

## Battery (optional)

The BAT connector feeds the charger. On this revision nothing routes battery
voltage to an ADC, so the panel cannot read the pack without a divider — two
resistors from BAT+ to **IO35**, which is free now that this board runs no
sensors:

```
BAT+ ---[ R1 ]---+--- IO35
                 |
                [ R2 ]
                 |
BAT- / GND ------+
```

100 kΩ / 100 kΩ gives a ratio of 2.0, halving 4.2 V to 2.1 V — inside ADC1's
range at 12 db. Equal resistors also mean the divider draws only ~20 µA, so it
won't meaningfully flatten the cell while the panel is off.

**Fit the divider before trusting the reading.** IO35 is input-only with no
internal pulldown, so an unwired pin floats and can report anything. With the
divider fitted and no pack attached it reads near zero through R2, which is how
the indicator knows to hide itself.

**Calibrate once:** meter the pack, compare against the `Battery Voltage`
sensor, and adjust `battery_divider` by the ratio between them. Resistor
tolerance is essentially the whole error.

**Before connecting a LiPo:** confirm this board actually charges the pack
rather than just drawing from it, and use a cell with a protection circuit.
An unprotected LiPo on a board that doesn't manage it is a fire risk, not a
runtime feature.

The indicator sits bottom-right, over every page:

| Shows | Meaning |
|---|---|
| `84% 3h` | Discharging, about 3 hours left |
| `84%` | Discharging, not enough readings yet for an estimate |
| `84% CHG` (blue) | Charging |
| `FULL` (blue) | Charged |
| hidden | No pack detected, or no divider fitted |

The runtime needs about 20 minutes of readings before it appears — it's a
measured discharge slope, not a nameplate figure, so it reflects your actual
brightness and Wi-Fi use.

Charging is detected by trend, not by a status pin — this board doesn't break
one out. The panel samples every five minutes and looks at which way the pack
is moving, so expect up to ten minutes before the label catches up after you
plug in or unplug. `binary_sensor.tank_monitor_v2_battery_charging` reports the
same thing to Home Assistant.

## If you ever convert it back to a controller

The pin map that worked on this revision: TDS IO35, heater IO27, fan IO18,
DS18B20 IO19 with a 4.7 kΩ pull-up to 3V3, BH1750 SDA/SCL on IO1/IO3 powered
from the 3-pin header's **3.3V, not the UART header's 5V**. Not IO22 — this
revision doesn't break it out. Not the speaker header — IO26 reaches it
through the audio amplifier.

# ESP32-WROOM-32 (`tank-monitor-w32`)

A controller with no screen — the same job as the C6, on a plain devkit.
Everything solders to the board's own header pins; there is no breakout.

Follow the C6 build above for technique: steps 2 (pre-tin), 3 (power splices),
6 (the pull-up), 8 (inspect) and 10 (before it goes near water) apply
unchanged. Only the pin numbers differ.

## Pin map

| Board pin | Goes to |
|---|---|
| GPIO34 | TDS `A` |
| GPIO4 | DS18B20 yellow (DQ), with the 4.7 kΩ pull-up to 3V3 |
| GPIO21 | BH1750 `SDA` |
| GPIO22 | BH1750 `SCL` |
| GPIO26 | Relay Ch1 `IN+` (heater) |
| GPIO27 | Relay Ch2 `IN+` (fan) |
| GND | `IN−` both channels, and every sensor ground |
| 3V3 | every sensor VCC |

Leave BH1750 `ADDR` unconnected — floating is 0x23, which the config expects.

## Why these pins, and which ones to avoid

This board has pins to spare, so the choices are about which are *safe*:

- **GPIO6–11** are the flash. Using them prevents boot.
- **GPIO0, 2, 12, 15** are strapping pins. A pull-up or pull-down at boot
  changes boot mode — a 4.7 kΩ probe pull-up on GPIO12 stops some boards
  booting at all, which is why the DS18B20 is on GPIO4.
- **GPIO34–39 are input only** with no internal pull-ups. Right for the TDS
  analog line, useless for a relay or a 1-Wire bus.
- **ADC2 cannot be read while Wi-Fi is on.** Any analog input must be on
  ADC1 (32–39). That is not a preference; ADC2 simply returns garbage.

GPIO25, 32 and 33 are left free on purpose — 32 and 33 are the remaining ADC1
pins, which is what a second analog probe (pH, ORP) would need.

## Differences from the C6

**It keeps a USB console.** The CYD has to disable serial because its I²C sits
on the UART pins; nothing here touches GPIO1/GPIO3, so this is the easiest of
the three boards to diagnose with `esphome logs`.

**No display, no backlight.** Home Assistant, the web UI at its own IP, and the
remote panel are the interfaces.

**Give it a different `device_name`** if it runs alongside the C6. That name
sets the MQTT topic prefix, discovery object ids, mDNS hostname and fallback AP
name at once — two boards answering to the same name overwrite each other's
entities as fast as they appear.

To let a remote panel read this board instead of the C6, uncomment
`packages/espnow_link.yaml` in the wrapper **and** point that panel's
`source_device` substitution at this device's name. The panel selects its
source by provider name, so two controllers can broadcast at once without
colliding — but a panel only listens to the one it was told about.

# ESP32-S3 mini (`tank-monitor-s3`)

A controller with no screen, on a board the size of a postage stamp. Covers
both the **Waveshare ESP32-S3-Zero** (23.5 × 18 mm) and the generic
**"ESP32-S3 SuperMini"** (22.5 × 18 mm) — same chip, same pin map, one
config in `boards/esp32s3-mini.yaml`.

Follow the C6 build above for technique: steps 2 (pre-tin), 3 (power
splices), 6 (the pull-up), 8 (inspect) and 10 (before it goes near water)
apply unchanged. Only the pin numbers and the two extra parts differ.

## Two parts the other boards do not need

| Part | Why |
|---|---|
| 100 µF electrolytic + 100 nF ceramic | across `3V3` and `GND`, as close to the board as they will sit. These boards brown out and reboot under Wi-Fi transmit load; this is the fix |
| 31 mm of 1.0 mm silver-plated wire | *optional* antenna mod — see below. Skip it until you have measured RSSI |

## Pin map

| Board pin | Goes to |
|---|---|
| GPIO1 | TDS `A` |
| GPIO2 | pH board analog out (blue on the Gravity cable) |
| GPIO5 | DS18B20 yellow (DQ), with the 4.7 kΩ pull-up to 3V3 |
| GPIO6 | BH1750 `SDA` |
| GPIO7 | BH1750 `SCL` |
| GPIO8 | Relay Ch1 `IN+` (heater) |
| GPIO9 | Relay Ch2 `IN+` (fan) |
| GND | `IN−` both channels, every sensor ground, and the caps |
| 3V3 | every sensor VCC, and the caps |

Leave BH1750 `ADDR` unconnected — floating is 0x23, which the config expects.

`GPIO4` is left free on purpose: it is the reserved ADC1 pin for an ORP
probe. `GPIO10` is the last ADC1 pin after that, then 11–13 for digital.

That is four wires on the 3V3 splice and six on GND — one more of each than
the C6 build, because of the pH board and the decoupling caps. Ten
conductors is past what one twisted joint holds reliably, so make it two
splices per rail joined by a short link, not one bundle.

**The pH board goes to 3V3, not 5V.** The SEN0169-**V2** is the
wide-voltage edition and outputs 0–3 V. The classic SEN0169 outputs 0–5 V
and will damage GPIO2. Check the board you actually received.

## Why these pins, and which ones to avoid

Only GPIO1–13 are used, because that is the range *both* boards break out.
The Zero also exposes 15–18, 21 and 43/44; the SuperMini does not.

Which pins are safe comes from ESPHome's validator (`gpio_esp32_s3.py`),
not from seller pinout diagrams:

- **GPIO26–32** are the in-package flash and PSRAM. ESPHome rejects them
  outright. No mini board breaks them out, which is why.
- **GPIO0, 3, 45, 46** are strapping. Only GPIO3 is on this header, so it
  is the one pin in 1–13 left alone. GPIO0 is the BOOT button.
- **GPIO19, 20** are USB-Serial-JTAG, which is this board's only console.
- **GPIO22–25** are not in the IO mux at all. Unusable on any S3.
- **ADC2 (GPIO11–20) cannot be read while Wi-Fi is on.** Every analog
  probe must be on ADC1, which is GPIO1–10. Not a preference — ADC2
  returns garbage.

**GPIO9–14 are ordinary GPIOs.** Several widely-copied pinout guides label
them "flash-dedicated"; that is carried over from octal-PSRAM S3 modules
and is wrong for the FH4R2. The fan relay sits on GPIO9.

The relays are deliberately **not** on GPIO43/44. Those are free now that
the console is on USB, but the ROM bootloader prints on TX at every reset,
and a few milliseconds of that on an optocoupled relay input is an audible
click of the heater on every boot.

## The antenna, which is the weak part

Both boards use a small 2.4 GHz ceramic antenna with a documented history
of short range and dropped links. On the S3-Zero, a paired-RSSI test
against an unmodified board measured **at least +10 dB** from a wire
antenna — roughly double the usable range — and thermal imaging showed the
stock regulator running hot from reflected power. SuperMini units have
also been reported shipping with the ceramic antenna mounted backwards.

This board is the ESP-NOW provider for the remote panel, and ESP-NOW
follows the Wi-Fi association, so a marginal link degrades the panel and
MQTT together. The control loop itself is unaffected — it runs on-device
and keeps regulating with the network down. Brownout *reboots* are the
real cost: the model, light profile and setpoint all persist, but each
reboot restarts the 900 s heater window mid-cycle and blanks the hourly
swing history for ten minutes.

So: fit the caps always, and check RSSI once the board is where the tank
is. Below about −70 dBm, do the wire mod — a 5 mm loop at the bottom of a
31 mm length, the loop fitted around both ends of the original antenna.

If neither appeals, a **XIAO ESP32-S3** is smaller again (21 × 17.5 mm) and
has a U.FL connector with an external antenna in the box, which removes the
problem rather than mitigating it. It breaks out 11 GPIO against the eight
used here, so it fits — with no room for a second I²C device that does not
share the bus.

## Differences from the C6

**No USB-UART bridge.** The USB-C port is wired straight to the S3's
USB-Serial-JTAG peripheral, so the board file sets
`logger: hardware_uart: USB_SERIAL_JTAG`. Without it the console would go
out on GPIO43/44 where nothing is listening — an open port and no output.
If the dashboard does not offer the port on first flash, hold BOOT while
plugging it in.

**Recalibrate pH and TDS.** `ph_v_high` and `ph_v_low` are volts
measured through *this board's* ADC, and the S3's converter is not the
C6's. Copying the numbers from another wrapper gives a wrong reading that
looks right — which is the exact failure that made the old monitor
useless. Each voltage travels with the pH it was measured at
(`ph_cal_high` / `ph_cal_low`); a voltage on its own is meaningless.

Pick the two buffers that **bracket the tank** and keep a third back as an
independent check — a glass electrode is linear from 4 to 10, so a third
calibration point buys nothing, but a tank at 7.4 calibrated on 6.86 and
4.00 is extrapolated above its highest cal point. With the NIST set
(4.00/6.86/9.18) that means calibrating on 9.18 and 6.86 and verifying
against 4.00. Recheck the TDS `k_factor` the same way.

**No display, no backlight.** Home Assistant, the web UI at its own IP, and
the remote panel are the interfaces.

**Give it a different `device_name`** if it runs alongside the C6. That
name sets the MQTT topic prefix, discovery object ids, mDNS hostname and
fallback AP name at once — two boards answering to the same name overwrite
each other's entities as fast as they appear.

To let a remote panel read this board instead of the C6, uncomment
`packages/espnow_link.yaml` in the wrapper **and** point that panel's
`source_device` substitution at this device's name.

# Freenove ESP32-S3 all-in-one, large tank (`tank-monitor-75-gallon`)

One board for the whole 75 gal: both heaters, the fan, both temperature
probes, TDS, pH, the floor leak sensor, lux and spectral. It replaces the
XIAO controller **and** the light pod. `boards/allinone-freenove.yaml`,
deployed by `tank-monitor-allinone-freenove-remote.yaml`.

Every device has its own GPIOs. The ESP32-S3 has exactly two I²C
controllers, so the two light sensors get one bus each and the ADS1115 is
gone: pH, TDS and leak read on the chip's own ADC, one pin each.

## Pin map

The Freenove board is labelled with GPIO numbers directly (DevKitC-1 layout).

| Device | Signal | GPIO | Harness wire (as built) |
|---|---|---|---|
| pH board | analog out | **1** | **blue** (single) |
| DS18B20 A (control) | data; 4.7 kΩ to 3V3 | **4** | **gray** |
| DS18B20 B (cross-check) | data; 4.7 kΩ to 3V3 | **5** | **white** |
| TDS board | `A` (analog out) | **6** | **purple** (single) |
| Leak sensor | sensor output; 2.2 MΩ + 100 nF from the pin to GND | **7** | **green** (single) |
| Heater A relay | control | **8** | **yellow** (single) |
| Heater B relay | control | **9** | **orange** |
| Fan relay | control | **10** | **brown** |
| BH1750 | SDA / SCL | **15 / 16** | **yellow / green** pair |
| AS7341 | SDA / SCL | **17 / 18** | **purple / blue** pair |

**Watch the repeated colors.** Yellow, green, purple and blue each appear
twice: once as a single wire and once in a sensor pair. The single yellow is
heater A, the yellow in the pair is the BH1750's SDA. The single green is the
leak sensor, the green in the pair is the BH1750's SCL. The single purple is
TDS, the purple in the pair is the AS7341's SDA. The single blue is pH, the
blue in the pair is the AS7341's SCL. Keep each pair twisted or taped
together and label the singles before they come off the board.

**On an ESP32-S3 DevKitC-1 instead:** same pin numbers, same header layout,
same firmware -- `boards/allinone-freenove.yaml` already builds for
`esp32-s3-devkitc-1`, and any flash size of 8 MB or more works. Wire it by
the GPIO column exactly as above. The only DevKitC difference is its RGB
LED, on GPIO38 or 48 depending on the board revision; neither is used here.

Everything except GPIO 1 is on the same header row. Leave these alone:
`0`, `3`, `45`, `46` (strapping), `35`–`37` (PSRAM), `19`/`20` (USB),
`43`/`44` (console), `38`–`40` (microSD), `2` and `48` (LEDs). GPIO 4–18 also
run to the camera connector. **GPIO 4 and 5 are the camera's SCCB bus and are
pulled up to 3V3 on the Freenove board**, fitted camera or not, so they carry
the 1-Wire probes (which want a pull-up anyway) and never an analog input.
Until 2026-09-28 TDS and leak sat on 4 and 5: TDS read ~2.33 V in air and the
leak read a flat 3.15 V ("wet") no matter what was wired to it.

The Freenove header has **one** `GND` pin, bottom right next to GPIO19 (USB
ports at the bottom). Bottom left is `5V` and top right is `TX`: this is where
it differs from a DevKitC-1, which has GND in both of those places.

## Power

One `3V3` pin and one `GND` pin feed seven devices, so power is still
spliced off the board (see the XIAO section's rails). **Give the two light
sensors their own 3.3 V**: a small 3.3 V regulator fed from the `5V` pin, or
a resettable fuse on their power lead. Their leads run up to the fixture,
and a short on one of them (it happened on 2026-09-17) must not brown out
the board that switches the heaters.

## Swapping it in

1. Flash it on the bench. Leave the XIAO controller running until then.
2. **Power the XIAO controller and the light pod off.** This board uses the
   same device name, and two devices on one name overwrite each other.
3. In Home Assistant, delete the **Tank Monitor 75 Gallon** and **Tank
   Monitor Light Pod** devices from the MQTT integration. Entity IDs are
   tied to the chip, so without this every entity comes back with `_2` and
   the automations keep pointing at the dead ones.
4. Power the new board. Check `I2C Devices` reads `BH1750 ok, AS7341 ok`.
5. Read `Controller BLE MAC` and put it in the display panel's wrapper.
6. **Recalibrate:** pH (Capture High/Low Point), TDS (Calibrate TDS),
   cross-calibrate the two temperature probes in one cup, and check
   `Leak Sensor Voltage` dry and wet against the leak thresholds.

# XIAO ESP32-S3, large tank (`tank-monitor-75-gallon`)

The second tank's controller. Same silicon as the 12-gal XIAO, a different
wet side: **two DS18B20 probes, two BH1750 light sensors, pH and TDS on an
ADS1115, and three relay channels** — heater A, heater B, fan. Config is
`boards/xiao-esp32s3-lg-dual.yaml`; wrapper is `tank-monitor-lg-remote.yaml`.

Follow the C6 build for technique: steps 2 (pre-tin), 8 (inspect) and 10
(before it goes near water) apply unchanged. The power step is **different**
— see below — because this board has roughly twice the conductors of any
other in this file.

## What you need

- The XIAO ESP32-S3 (8 MB flash / 8 MB PSRAM — check the label, the S3 mini
  is a different board and a different config)
- ADS1115 breakout (16-bit, 4-channel, I2C)
- 2 × DS18B20 waterproof probes
- 2 × BH1750 breakouts
- Level Sense LS-2600 floor leak sensor (6 ft lead) + 2 × 1 MΩ resistors (from the kit, in series) + 100 nF ceramic
- DFRobot Gravity TDS board (SEN0244) + probe
- DFRobot Gravity pH board **SEN0169-V2** + BNC probe — the V2 specifically,
  it outputs 0–3 V. The classic SEN0169 outputs 0–5 V and will damage the
  ADS1115 at the 3.3 V rail it must run on
- D-1585TL 4-channel IoT relay outlet (the 4-outlet sibling of the D-1584TL
  you already run)
- 2 × 4.7 kΩ resistors, 1/4 W
- A scrap of perfboard, ~20 × 40 mm, for the power rails
- 26–28 AWG silicone hookup wire, heat shrink, iron, multimeter — as for the C6

Optional: 100 µF electrolytic + 100 nF ceramic across 3V3/GND at the rail.
The XIAO regulates better than the S3 mini and the 12-gal XIAO has run
without them; cheap insurance if you have them in the drawer.

## Read this before you pick up the iron

**The pad labels are not GPIO numbers.** The XIAO is silkscreened `D0`–`D10`
and those are *not* the GPIOs the config uses — `D3` is GPIO4, `D8` is GPIO7.
Wiring to the pad whose printed number matches a GPIO lands on the wrong pin,
and every symptom of that is silent: a probe on the wrong bus reports "No
devices", an analog input on the wrong pad reads plausible nonsense. **Wire
by the `D` column of the table below and nothing else.**

**`D2` stays empty.** It is GPIO3, an S3 strapping pin. Nothing may hold it
at a level during boot.

**Ignore the small alternate-function labels.** Next to the `D` numbers the
silkscreen also prints `SDA` beside `D4` and `SCL` beside `D5` — the chip's
*default* I2C pair — and `TX`/`RX` beside `D6`/`D7`. This config does **not**
use them that way: I2C is on `D6`/`D7`, `D4` is a relay, `D5` is a probe.
Wire I2C to the pads marked `SDA`/`SCL` and you have put the light sensors
on the heater-B relay line. Follow the `D` number, nothing else.

**The ADS1115 runs from 3V3, not 5V.** Its I2C logic threshold is 0.7 × VDD:
at 5 V that is 3.5 V, and the XIAO drives 3.3 V, so highs are marginal and it
fails intermittently. Its absolute-max analog input is VDD + 0.3 V, so the
3.3 V rail also caps what the Gravity boards may feed it.

## Pin map

Top view, USB-C at the top. Left column `D0`–`D6` top to bottom; right column
`5V`, `GND`, `3V3`, `D10`, `D9`, `D8`, `D7` top to bottom.

| Pad | GPIO | Goes to |
|---|---|---|
| `D0` | 1 | DS18B20 **B** yellow (DQ) — cross-check probe, bus B |
| `D1` | 2 | *spare* (ADC1) |
| `D2` | 3 | **nothing — strapping pin** |
| `D3` | 4 | *spare* (ADC1) |
| `D4` | 5 | Relay Ch2 `IN+` — **heater B** |
| `D5` | 6 | DS18B20 **A** yellow (DQ) — control probe, bus A |
| `D6` | 43 | I2C `SDA` — ADS1115, both BH1750s |
| `D7` | 44 | I2C `SCL` — ADS1115, both BH1750s |
| `D8` | 7 | Relay Ch1 `IN+` — **heater A** |
| `D9` | 8 | Relay Ch3 `IN+` — **fan(s)** |
| `D10` | 9 | *spare* (ADC1) |
| `3V3` | — | the 3V3 rail (one pigtail) |
| `GND` | — | the GND rail (one pigtail) |
| `5V` | — | unused |

Heater A and probe A are the **same half of the tank**; B and B the other.
That pairing is a wiring fact the firmware cannot verify, and if it is
backwards every gradient reading points at the wrong end. Label the probe
leads before they go in the water.

I2C is on `D6`/`D7` = GPIO43/44, which are also UART0. That is fine: the
XIAO's console is native USB, so UART0 is free. It is why the **relays are
not** on those pads — the ROM bootloader prints on TX at every reset, and a
few milliseconds of that on an optocoupled relay input is an audible click
of the heater on every boot.

## Power distribution — build a rail, do not splice

Count the conductors:

| Rail | Wires |
|---|---|
| 3V3 | DS18B20 A, DS18B20 B, BH1750 A, BH1750 B, BH1750 B `ADDR`, ADS1115 `VDD`, TDS board, pH board, pull-up A, pull-up B — **10** |
| GND | DS18B20 A, DS18B20 B, BH1750 A, BH1750 B, ADS1115 `GND`, ADS1115 `ADDR`, TDS board, pH board, relay `IN−` — **9** |

Twenty conductors. (The leak sensor adds none — it lands entirely on the
ADS1115 breakout, step 7b.) The C6 section says ten is past what one twisted joint
holds; this is twice that. So: **perfboard**.

Take the scrap of perfboard. Pick two rows a few holes apart and bridge each
row with a run of solder or a length of bare bus wire — that gives you a
3V3 rail and a GND rail, each with a dozen tinned holes. Solder one pigtail
from each rail to the XIAO's `3V3` and `GND` pads. Every sensor's power lead
then goes to a hole on the appropriate rail, one wire per hole, each with
its own joint.

Mark which rail is which with a permanent marker before the first wire goes
on. A 3V3/GND swap on a rail takes every sensor with it.

If you are using the decoupling caps, they go across the two rails on the
perfboard, right where the XIAO pigtails land.

## 1. Prep and pre-tin

C6 steps 1–2. Tin only the pads in the table: `D0`, `D4`, `D5`, `D6`, `D7`,
`D8`, `D9`, `3V3`, `GND`. Leave `D2` untouched — bare, untinned, nothing
near it.

## 2. Build the rails

As above. Pigtails to the XIAO first, then check continuity from each rail
to its pad with the meter. Then nothing else on the rails until step 3.

## 3. The ADS1115 — first on the bus, closest to the board

This is the one I2C device that carries analog signals, so it sits **as
close to the XIAO as the wiring allows** — a few centimetres of `SDA`/`SCL`,
not a run.

| ADS1115 pin | Goes to |
|---|---|
| `VDD` | 3V3 rail |
| `GND` | GND rail |
| `SDA` | `D6` |
| `SCL` | `D7` |
| `ADDR` | GND rail — **explicitly**, not floating. 0x48 |
| `ALRT` | unconnected |
| `A0` | TDS board signal (step 4) |
| `A1` | unconnected — was pH; the channel failed 2026-09-24, leave it unused |
| `A2` | leak sensor (step 7b) |
| `A3` | unconnected |

The BH1750s' `SDA`/`SCL` (step 5) need the same two lines. Land them on the
**ADS1115 breakout's `SDA` and `SCL` pins**, not back on the XIAO — it is
one bus, so the breakout's header is electrically the same point as `D6`/
`D7`, and it means the XIAO's pads are soldered once and never reopened.

## 4. TDS into the ADS1115 (pH is on the light pod)

The TDS board (SEN0244) runs from the **3V3 rail** and outputs 0–2.3 V,
under the ADS1115's 3.6 V ceiling.

| Board | Wire | Goes to |
|---|---|---|
| TDS | red / `+` | 3V3 rail |
| TDS | black / `−` | GND rail |
| TDS | `A` | ADS1115 `A0` |

**Route the signal wire away from the relay module's mains cord.**

**The pH board is not wired here any more.** It moved to the light pod on
2026-09-24 after its channel on this board failed (A1 drifted to the rail
mid-run; on A3 it read an impossible 0.51 V, so the fault was upstream of
the ADS1115). The pod reads it on its own ADC and sends the voltage to this
controller over BLE, where `packages/ph.yaml` does the maths exactly as
before. See the light pod section for its wiring.

## 5. The two BH1750s and their addresses

They share the I2C bus with the ADS1115 and tell themselves apart by the
`ADDR` pin. **This is the whole trick** — two identical boards, one address
pin each, wired opposite:

| | `VCC` | `GND` | `SDA` | `SCL` | `ADDR` | Address |
|---|---|---|---|---|---|---|
| BH1750 **A** | 3V3 rail | GND rail | `D6` | `D7` | **unconnected** | 0x23 |
| BH1750 **B** | 3V3 rail | GND rail | `D6` | `D7` | **3V3 rail** | 0x5C |

Get both `ADDR` pins the same way round and the I2C scan shows one device
where you expect two — and the config's second sensor never publishes.

These two sit at opposite ends of a 48" tank, so each `SDA`/`SCL` pair is a
4–5 ft run. I2C is not built for that; the board file already runs the bus
at **10 kHz** (down from the 50 kHz default) to buy the capacitance margin
a run that long needs. Your side of the bargain:

- The cable on hand is **22 AWG 4-conductor UL 2464** (stranded, PVC, no
  shield, no twist). It works at 10 kHz — roughly 20 pF/ft, so both runs
  together stay well inside the bus's 400 pF budget — but with untwisted
  conductors the clock edges couple into the data line if the two lie
  side by side. So look at the cut end: the four cores sit in a square.
  Put `SDA` and `SCL` on **diagonally opposite** cores, and `3V3`/`GND` on
  the other diagonal, so a supply line sits between the two signals in
  every direction. Same assignment at both ends, obviously.
- **Better: Cat6.** Any Cat6 — plain UTP is fine; the twist is what matters,
  a shield (S/FTP) is a bonus. A 10 ft patch cable cut in half gives both
  runs. Use it like this — each signal twisted with a DC line, never the two
  signals twisted together:

  | Pair | Use |
  |---|---|
  | blue / blue-white | `SDA` / `GND` |
  | orange / orange-white | `SCL` / `3V3` |
  | green / green-white | second `GND` / second `3V3` (parallel the supply) |
  | brown / brown-white | unused |
  | drain + braid (shielded cable only) | `GND` at the **board end only** — leave it floating at the sensor |

  Grounding a shield at both ends makes a loop that picks up exactly the
  relay noise the shield was meant to keep out. Solid-core bulk Cat6 solders
  into the perfboard rail fine but hates being flexed — strain-relieve it
  where it leaves the board.
- **Route it away from the heater cords and the relay module.** A slow clock
  buys capacitance margin, not noise immunity; a relay snapping next to an
  unshielded I2C pair is a corrupted lux reading, not an error.
- The GY-302 breakouts carry their own pull-ups, so add none. If the scan
  is intermittent, 2.2 kΩ from `SDA` and `SCL` to 3V3 at the *board* end.

If one sensor still comes and goes in the log after that, the fix is a
differential I2C extender — a PCA9615 board (SparkFun QwiicBus) at the XIAO
and one at each sensor, which carries I2C over ordinary twisted pair for
tens of metres. Do not chase it with thicker wire or a faster clock.

## 6. Two 1-Wire buses, two pull-ups

Two probes, and they are **deliberately on separate buses** so neither
needs an address in the config and a flooded probe takes down only itself.
Each bus is exactly the C6's step 6, done twice:

| Probe | Red | Black | Yellow (DQ) | 4.7 kΩ |
|---|---|---|---|---|
| DS18B20 **A** (control, heater-A half) | 3V3 rail | GND rail | `D5` | between `D5` and the 3V3 rail |
| DS18B20 **B** (cross-check, heater-B half) | 3V3 rail | GND rail | `D0` | between `D0` and the 3V3 rail |

Pull-up at the *board* end, not out at the probe. Sleeve both resistor legs.
Without it that bus reports "No devices, can't auto-select address", which
is indistinguishable from the probe being on the wrong pad.

Label the probe leads **A** and **B** now, at the board, before they are
routed. Once they are in the tank they look identical.

## 7. Relay control, three channels

Low-voltage terminals only. Do not open the module or touch its mains side
— it has its own cord. The D-1585TL takes 3–120 V DC on its control
terminals and is **active-high**, so the XIAO's 3.3 V drives it directly.

| XIAO pad | D-1585TL |
|---|---|
| `D8` | Channel 1 `IN+` — **heater A** |
| `D4` | Channel 2 `IN+` — **heater B** |
| `D9` | Channel 3 `IN+` — **fan(s)**, all in parallel on this one outlet |
| GND rail | `IN−` on channels 1, 2 and 3, jumpered together |
| — | Channel 4 — spare, nothing connected |

Note `D4` for heater B, not `D3` — `D3` is a spare ADC pin and `D4` is
GPIO5. Easy to land one pad over.

3.3 V is the **bottom** of the module's 3–120 V control range. It works —
your 2-channel D-1584TL runs on it today — but it means the internal opto
LED is at minimum forward current. If a channel ever latches on and will not
release, that is the symptom, and the fix is feeding that `IN+` through the
GPIO from the XIAO's `5V` pad rather than 3.3 V. Not a reason to change
anything now.

## 7b. Floor leak sensor — on the ADS1115, nothing on the XIAO

The LS-2600 is not a bare pair of tabs. There is a transistor behind them:
the datasheet calls it *open circuit when dry, roughly 1.4 MΩ when wet*,
and it is **polarised** — red to +V, the other wire (black here, white on
some units) to the input. Wet, it sources current from red to black. So the input wants a pull-**down**, and reads
0 V dry and 1–2 V wet. (A pull-up, the obvious thing for a "switch", fails
here: against the sensor's 1.4 MΩ the wet and dry voltages end up within
a volt of each other.)

The ADS1115 is already on the bus with `A2` and `A3` unused, so the sensor
is read as a voltage on `A2` and every connection lands on the **breakout's
own header**. The XIAO is not touched.

| | Goes to |
|---|---|
| **Red** | ADS1115 `VDD` pin (3V3) |
| **Black** (white on some units) | ADS1115 `A2` |
| 2 × 1 MΩ **in series** (= 2 MΩ; one 1 MΩ alone also works) | between `A2` and the breakout's `GND` pin |
| 100 nF ceramic | between `A2` and the breakout's `GND` pin, as close to `A2` as it sits |

Three things on one header pin: black lead, resistor leg, cap leg. Tin
them together in one go. "In series" = twist one leg of each resistor
together and solder; the two free legs are the ends. Get red and black the right way round — reversed,
the transistor never conducts and the sensor is silently dead.

The config calls it a leak above **1.2 V** and dry again below **0.8 V** —
the gap is hysteresis, so a floor that hovers near one line cannot
flicker the alarm — held 5 s before believing it and 10 s before clearing.
Those two numbers are `leak_on_v` / `leak_off_v` substitutions if your
floor reads differently: measured here, wet was 2.0–2.7 V, dry on the
bench 0.0 V, and dry on sealed hardwood beside the heater cords 0.2–0.5 V.
`Leak Sensor Voltage` is published as a diagnostic so you can see where
yours sits. The cap matters: a megohm node on 6 ft of cable is an antenna
without it, and that 0.2–0.5 V floor reading is largely what it picks up.

**On 3V3 instead of the rated 5 V, deliberately.** 3V3 keeps a wet sensor's
output under the ADS1115's absolute-maximum input (VDD + 0.3 V) with
nothing else in the circuit; on 5 V a wet sensor can push 4 V+ into `A2`,
which kills the ADC. A transistor follower does not mind 3V3. If it turns
out this one does — `Leak Sensor Voltage` stays at 0 with the tabs wet in
step 9 — the fallback is red on the XIAO's `5V` pad and a 1 MΩ in series
between black and `A2`. That is the one case that reopens the board.

Put the sensor where water collects first — the lowest point under the
tank. The 6 ft lead reaches from wherever the board ends up.

## 8. Inspect

C6 step 8. Then three checks specific to this build, all with the board
**unpowered**:

- Meter from `D2` to everything. It should be open to all of it.
- Meter from the 3V3 rail to the GND rail. Open. If it beeps, one of the
  twenty wires is on the wrong rail — find it now, not with smoke.
- Meter from BH1750 A's `ADDR` to BH1750 B's `ADDR`. Open. If they are
  connected, they are on the same address.
- Meter from ADS1115 `A2` to its `GND` pin: the pull-down, ~2 MΩ. `A2`
  to `VDD`: open — if it reads low, red and black are swapped or the
  sensor is wet. (There is a transistor in the sensor, so a wet-finger
  test with the meter proves nothing; that check is in step 9, powered.)

## 9. Power up in stages — what the log should say

USB-C from a wall adapter. Flash `tank-monitor-lg-remote.yaml` and watch the
serial log. In order:

**I2C scan** — the first thing you want to see, and it names all three:

```
[I][i2c.idf]: Found i2c device at address 0x23
[I][i2c.idf]: Found i2c device at address 0x48
[I][i2c.idf]: Found i2c device at address 0x5C
```

One missing is a wiring fault on that device. `0x23` present and `0x5C`
absent is BH1750 B's `ADDR` not reaching 3V3. `0x48` absent is the ADS1115
— check its `VDD` is on 3V3 and `ADDR` is actually tied to GND.

**Two 1-Wire buses**, each reporting one device:

```
[I][one_wire.gpio]: Found devices:
[I][one_wire.gpio]:   0x...   (bus on GPIO6)
[I][one_wire.gpio]: Found devices:
[I][one_wire.gpio]:   0x...   (bus on GPIO1)
```

"No devices" on one bus and not the other is that bus's pull-up or its
yellow wire on the wrong pad.

**Then** check Home Assistant: `Water Temperature Left` and `Water
Temperature Right` both reporting, `TDS` and `pH` present and not NaN,
`I2C Devices` reading `ADS1115 ok`, `Leak` off, and — the one people
forget — the relay binary sensors present and **off**: `Heater` (the
pair), `Heater Left`, `Heater Right` and `Fan`. The side names come from
`side_a_name` / `side_b_name` in the wrapper; if you changed those, the
entities follow.

**Put it in Filling mode now** — `Tank Mode` on the device page — and
leave it there until the tank is full and both probes are under water.
Filling holds every output off and judges nothing: probes in air read
room temperature and disagree, a Jager out of water must not be powered,
and the learner must not watch any of it. Nothing you do on the bench
can trip a fault while it is set. Switch to `Cycling` once it is full
(regulates to `Cycling Target`, 82 °F by default, without touching your
real setpoint), and `Normal` when the cycle is done.

**Then the leak sensor**, which is the one check that needs power. `Leak
Sensor Voltage` (under diagnostics) should sit near **0 V** with the tabs
dry (up to ~0.5 V once it is lying on a floor is normal). Wet a fingertip
and hold it across both tabs: it climbs to **2–3 V** and after 5 s `Leak`
turns on. Dry the tabs, and 10 s later it clears.
If it stays at 0 V wet, first check red is on `VDD` and black on `A2` —
swapped, the sensor is silently dead. If that is right, this sensor will
not wake on 3V3: see §7b for the 5 V fallback.

**Then** the relays. From HA, raise the setpoint a few degrees above the
water temperature and watch `Heater Left` and `Heater Right` go on
**together** — both, at the same moment. They share one duty and one
phase-locked window. If only one goes, its `IN+` is on the wrong pad.

**This can take up to fifteen minutes.** The heaters are driven by a
time-proportional window of 900 s, and a duty change is picked up at the
next window boundary, not instantly. Wait it out before deciding something
is wrong — and listen for the relay click, which is unmistakable. Then drop
the setpoint and watch both release, again within a window.

## 10. Before it goes near water

C6 step 10, then two things this board needs that the others did not:

**Cross-calibrate the probes in one cup.** Two DS18B20 are ±0.5 °C absolute
and can read nearly a degree apart in identical water. Put both in the same
glass, wait ten minutes, and set `Cal Temp Offset B` until they agree. Every
gradient reading on this tank is downstream of that number, and the
`Probe Disagreement` alarm fires off it.

**Recalibrate pH and TDS.** The stored calibration in NVS is in volts read by
a *different* ADC, and it survives a flash. (pH is now read by the light
pod's ADC, so moving it counts as a converter change too.) The C6 → S3 swap moved TDS by
~30 % for exactly this reason. Both calibration procedures are in the
README; do them before believing any chemistry number this board reports.

Then set `side_a_name` / `side_b_name` in the wrapper to match how you
actually mounted things, and label the outside of the tank to match.

# Light pod (`tank-monitor-light-pod`)

Two light sensors and the pH board, no actuators. Runs on a **Seeed XIAO
ESP32-S3** (`boards/xiao-esp32s3-light-pod.yaml`), deployed by
`tank-monitor-light-pod-remote.yaml`. A **SparkFun Qwiic Pocket ESP32-C6**
build (`boards/sparkfun-esp32c6-pocket-light-pod.yaml`) also exists but is
not deployed. Both board files pull in the same `packages/light_pod.yaml`,
which holds all the sensor and BLE logic, so the two cannot drift apart.

It answers two different questions with two different parts, and the answers
travel by two different paths:

| Part | Answers | Goes to | How |
|---|---|---|---|
| BH1750 (0x23) | *how much* light, in lux | the 75 gal controller | BLE, peer to peer |
| AS7341 (0x39) | *which channels* are on | the controller **and** Home Assistant | BLE (compact) + MQTT (all 10 bands) |

Lux is a control input — it feeds the thermal model's light-gain term — so it
must not depend on the broker, Home Assistant or the router, and it doesn't.

The spectral side goes both ways. Home Assistant gets all ten channels over
MQTT for history and channel verification. The controller gets a compact
subset over the same BLE frame as lux, because one spectral number —
**NIR/clear** — is something the control loop can genuinely act on. See the
daylight reference below.

## The BLE frame

```
L,<lux>,<blue%>,<red%>,<nir×1000>        e.g.  L,412,21,32,4
```

Five fields, all integers, **never more than 19 bytes.** That size is
deliberate: a BLE write carries 20 bytes of payload until MTU negotiation
succeeds, and while ESPHome requests a larger MTU on connect, the granted size
is whatever both ends agree — not a promise. A frame that fits the default
works however that lands.

Green is not sent. The three shares cover all eight bands and sum to 100, so
the controller reconstructs it as `100 − blue − red`. Blue and red are the ends
of the spectrum and the channels actually being tuned; green is the inferable
one.

pH travels in a second frame on the same characteristic, `P,<volts × 10000>`
(e.g. `P,14803` = 1.4803 V), sent after `L` in the same connection. It is
separate because `L` already fills a 20-byte write.

`-1` in a spectral field means the AS7341 had nothing yet — it updates slower
than the BH1750, and lux must not wait on it.

## What you need

| Part | Notes |
|---|---|
| Seeed XIAO ESP32-S3 | Same board as both controllers. Pads are D0–D10 and those are **not** GPIO numbers |
| BH1750 / GY-302 | Leave `ADDR` unconnected for 0x23 |
| AS7341 breakout | Address fixed at 0x39 |
| DFRobot Gravity pH board SEN0169-V2 + probe | Moved here from the controller |
| Header pins, hookup wire, heat shrink | Headers on the XIAO and both sensors; power is spliced off-board |
| A rigid bracket | See mounting. This matters more than the wiring |

## Wiring (XIAO ESP32-S3)

Hold the XIAO **USB-C up, components facing you**. Left column top to bottom
is `D0`–`D6`; right column top to bottom is `5V`, `GND`, `3V3`, `D10`, `D9`,
`D8`, `D7`.

| XIAO pin | GPIO | Goes to |
|---|---|---|
| `3V3` (right, 3rd) | — | BH1750 `VCC`, AS7341 `VIN`/`VCC`, pH board red (+) |
| `GND` (right, 2nd) | — | BH1750 `GND`, AS7341 `GND`, pH board black (−) |
| `D4` (left, 5th) | 5 | BH1750 `SDA`, AS7341 `SDA` |
| `D5` (left, 6th) | 6 | BH1750 `SCL`, AS7341 `SCL` |
| `D3` (left, 4th) | 4 | pH board blue (analog out) |

Leave empty: `5V`, `D2` (GPIO3, a strapping pin), the BH1750's `ADDR`, and
the AS7341's `INT`/`GPIO`/`LDR` pins.

`3V3` and `GND` each feed three boards and `D4`/`D5` each feed two, but each
XIAO pin takes one wire. **Join them off the board**, same as the
controller: twist the wires going to the same signal together with one
pigtail, solder, heat-shrink, and put only the pigtail on the XIAO pin.

```
BH1750 VCC ─┐
AS7341 VIN ─┼─[ solder + heat shrink ]── pigtail ──► XIAO 3V3
pH red (+) ─┘
```

Same for `GND` (three wires), `SDA` (two) and `SCL` (two).

**Before the first power-up**, meter continuity between the `3V3` and `GND`
pigtails. It must not beep. A short there is what browned out the rail on
the first BH1750 attempt.

**Leave the BH1750's `ADDR` pin alone.** The 0x5C jumper is only needed when
two of them share a bus, and that hand-soldered ADDR-to-VCC splice is exactly
what shorted the 3V3 rail on the previous attempt. One sensor, no splice.

### How pH gets from the pod to Home Assistant

The pod does **not** compute pH. It sends the pH board's voltage to the
controller every minute (`P,<volts × 10000>` on the same BLE characteristic
as lux), and the controller's `packages/ph.yaml` applies the calibration and
temperature compensation and publishes `Water pH` as it always has. The pod
also publishes its own `pH Board Voltage` diagnostic: if that moves while
`Water pH` is blank, the link is down; if both are flat, it is the probe.

**Recalibrate after the move** with the controller's `Capture High Point` /
`Capture Low Point` buttons (procedure in `packages/ph.yaml`). The stored
calibration was measured through the controller's ADS1115; the pod's ADC
reads the same board differently. The pod pushes once a minute, so leave
the probe in each buffer at least two minutes before pressing capture.

**3.3 V, not 5 V**, for the pH board: the V2 runs on 3.3 V and its output
then stays inside the ADC's range.

Give the pod its **own USB charger**, not a second port on the controller's.
Separate supplies are what take the electrode off the ground it used to
share with the TDS probe and the heater relays.

## The controller must be flashed too

The pod pushes lux into a characteristic on the controller's existing BLE
server. That needs a controller build carrying `max_clients: 2`
(`packages/ble_link_v3.yaml`) — **ESPHome's BLE server allows one client by
default, and the 4.3" panel is already holding it.** Without it the pod will
advertise, connect-attempt, and never attach.

Order doesn't matter. Flash the pod first and it simply fails to connect until
the controller catches up; flash the controller first and `tank_lux` stays NaN
until the pod arrives, which is how the tank has run since the BH1750s came
out. Neither state is harmful.

Set `controller_mac` in the pod wrapper from
`sensor.tank_monitor_75_gallon_controller_ble_mac`, or from the controller's
boot log. **Do not compute it.** On an ESP32-S3 the BLE MAC is the WiFi MAC + 2
in the last octet, but that is an observation, not a promise.

## Mounting — this is the calibration

Everything the AS7341 produces is relative, so the geometry is the only thing
making one week's reading comparable to the next.

1. **Fix it permanently.** A sensor that shifts turns week-over-week comparison
   into noise, and nothing in the data will say it moved.
2. **Face it up at the fixture.** Never down at the water — that measures
   reflections off a moving surface, which vary with agitation, clarity and
   substrate, three things independent of the lamp.
3. **No glass in the light path.** A lid *beneath* the sensor is a splash
   shield and an asset. A lid *above* it is condensation and mineral film — a
   slowly varying attenuation indistinguishable from the lamp dimming, with
   step recoveries every time you clean it.
4. **Shield the window side.** Daylight is broadband and the photoperiod runs
   09:00–16:00, straight through the brightest part of the day.
5. **Out of the aerosol plume.** Bubbler mist deposits mineral film on the
   optical window, which on a relative sensor reads as the lamp fading.

The centre brace, on top of any lid, facing up, is a good spot: rigid, centred
under the bar where the emitters are well mixed, and away from the back-corner
returns.

## Power up

No staged power-up — nothing here can cook a tank. Flash it and check the boot
log for both addresses:

```
Found i2c device at address 0x23
Found i2c device at address 0x39
```

Neither found means SDA and SCL are swapped: change `i2c_sda` / `i2c_scl` in
the wrapper and reflash before reaching for the iron. One found means that
sensor's wiring is fine and the other's is not.

Then watch `sensor.tank_monitor_75_gallon_light_link_age` on the controller. It
should sit under 60 s. If it climbs without bound, the pod is reading light but
not reaching the controller — check `controller_mac` and that the controller is
running a `max_clients: 2` build.

## Set the exposure once, then leave it

`as7341_gain`, `as7341_atime` and `as7341_astep` decide what a "count" means.
Raw band values scale with all three, so **changing any of them rebases every
historical reading.** Treat it like recalibrating a probe: do it deliberately,
and write down the date.

Gain ships at `X2`, below the `X8` default, because this sits under a 138 W
fixture. Check `Spectral Saturated` after the first full-brightness
photoperiod:

- **Saturated on** → drop gain one step. A pinned channel reads a ceiling, not
  a measurement, and reports as "lots of red" entirely plausibly.
- **Every band in the low hundreds at full output** → raise it one step.

## The daylight reference learns itself

The photoperiod runs 09:00–16:00, straight through the brightest part of the
day, so lux over this tank is fixture **plus** sunshine and a BH1750 cannot
tell them apart. Left uncorrected, the thermal model learns to attribute
room-warming daylight to a fixture that was switched off.

There is nothing to configure for this. The reference maintains itself off a
physical invariant:

> The fixture emits essentially no near-infrared; sunlight is full of it. So
> fixture light lands almost entirely in `clear` and barely at all in NIR —
> which means turning the lamp **on** can only push NIR/clear **down**. Fixture
> light dilutes the ratio; it can never inflate it.

So the highest ratio ever observed is the purest daylight sample available, and
the controller simply keeps it. No sunny-afternoon ritual, no threshold typed
into a wrapper, no reflash. It decays on about a 16-day half-life so the
reference follows the seasons, a dirtying window or a moved sensor rather than
being pinned by one bright afternoon in September.

Samples are only taken above 50 lux — in a dark room both NIR and clear are
near zero and their ratio is noise, which would otherwise ratchet the reference
up on nothing at all.

**Both error directions are safe**, which is why this is allowed near a control
input:

| Reference is | Effect | Recovery |
|---|---|---|
| too high | correction under-fires, lux passes closer to raw | decays back down |
| too low | — | next brighter sample raises it immediately |
| not set yet | pass-through, today's behaviour exactly | first daylight sets it |

Watch it as **Daylight NIR Reference** (diagnostic). It reads unavailable until
the first daylight sample lands. If it ever looks wrong — sensor moved, window
changed — press **Relearn Daylight Reference** and it starts over from
pass-through.

## Reading it

Use the three shares — **Blue**, **Green**, **Red** — not the raw bands. They
are ratios over all eight visible channels, so they are independent of gain and
exposure and sum to 100 %. A commanded channel change moves them; a cloud past
the window does not.

To verify a phase push: note `Red Share`, change phase, check it moved. If
commanded red went up and the share did not, the push did not land.

**What this cannot tell you:** PAR. The counts are uncalibrated ADC values, not
micromoles, and `Spectral Visible Total` carries no unit for exactly that
reason. The BH1750 beside it is what reports in a real unit, and it is the only
one wired to `tank_lux`.

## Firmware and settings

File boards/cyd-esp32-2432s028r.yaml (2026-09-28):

# "CYD" ESP32-2432S028R -- ESP32-WROOM-32E with a 2.8" 240x320 ILI9341 and
# a resistive XPT2046 touch panel.
#
# DISPLAY ONLY. Pair with packages/base.yaml, packages/remote_display.yaml
# and packages/chemistry.yaml -- NOT control.yaml or sensors.yaml.
#
# ---------------------------------------------------------------
# Why this board runs no sensors
# ---------------------------------------------------------------
# Almost every GPIO here is spoken for internally: 12-15 display,
# 25/32/33/36/39 touch, 4/16/17 RGB LED, 21 backlight, 26 speaker,
# 34 onboard LDR, 5/18/19/23 microSD. What reaches a connector on this
# revision is IO35, the SPI header (IO23/19/18/27) and the UART pins.
#
# That is barely enough for a probe, a TDS meter, a light sensor and two
# relays, and getting there meant repurposing the microSD bus, powering
# the light sensor off a pin that also flashes the chip, and metering the
# speaker header to find out whether it reached the pin or an amplifier.
# Every one of those is a real constraint fighting a real requirement.
#
# So the roles are split instead. The C6 keeps the probe, the relays and
# the control loop -- the tank is regulated by hardware bolted to it, and
# keeps being regulated whether or not this panel is plugged in. This
# board subscribes to the C6's values and draws them. It needs no GPIO at
# all beyond its own screen: no pull-up, no relay wiring, no ADC pin, and
# the microSD slot is free for use again.
#
# The sensor pin map that used to live here is gone with the hardware it
# described. If this board is ever converted back to a controller, the
# assignment was: TDS IO35, heater IO27, fan IO18, DS18B20 IO19 (with a
# 4.7k pull-up), BH1750 on IO1/IO3, and NOT IO22 -- which this revision
# does not break out -- and NOT the speaker header, which reaches IO26
# through the audio amplifier.
#
# ---------------------------------------------------------------
# Battery (optional)
# ---------------------------------------------------------------
# The BAT connector on this board feeds the charger; on this revision
# nothing routes battery voltage to an ADC, so the panel cannot read it
# without a divider. Two resistors from BAT+ to IO35 (free now that this
# board runs no sensors) and battery_divider set to the ratio:
#
#   BAT+ ---[ R1 ]---+--- IO35
#                    |
#                   [ R2 ]
#                    |
#   BAT- / GND ------+
#
# 100k/100k gives a ratio of 2.0 and halves 4.2V to 2.1V, inside ADC1's
# range at 12db. Equal resistors also mean the divider itself only draws
# ~20uA, which will not meaningfully flatten the cell.
#
# With the divider fitted and no battery attached the pin reads near zero
# through R2, which is how the indicator knows to hide itself. WITHOUT the
# divider IO35 floats and can read anything -- there is no internal pulldown
# on 34-39 -- so fit it before trusting the number.
#
# Calibrate once: meter the pack, compare with the Battery Voltage sensor,
# and adjust battery_divider by the ratio between them. Resistor tolerance
# is the whole error here.
substitutions:
  battery_divider: "2.0"
  # Below this, assume no pack is connected and hide the indicator.
  battery_absent_v: "2.5"

esp32:
  board: esp32dev
  flash_size: 4MB
  framework:
    type: esp-idf

# Overrides packages/base.yaml. 0 disables the UART entirely so the logger
# does not fight the BH1750 for IO1/IO3.
logger:
  level: INFO
  baud_rate: 0

# ESPHome's default MQTT unique_id generator is "legacy", which builds
# "ESP" + component_type + object_id and includes neither the device name
# nor the MAC. Two boards running the same package set therefore publish
# byte-identical unique_ids -- "ESPsensorwater_temperature" on both -- and
# Home Assistant silently drops the second registration. The symptom is
# entities that never appear, with no error anywhere, and renaming the
# device does not help because the name was never part of the id.
#
# Only the chemistry sensors got through, being the sole entities the
# other board does not also have.
#
# "mac" generates MAC + component_type + hash(friendly_name), which is
# unique per board. Set here rather than in base.yaml on purpose: changing
# it on the C6 would regenerate every one of its unique_ids, orphaning its
# existing entities and their history.
mqtt:
  discovery_unique_id_generator: mac
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

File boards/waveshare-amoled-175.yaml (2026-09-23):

# Waveshare ESP32-S3-Touch-AMOLED-1.75 -- round remote panel.
#
# Display-only, exactly like the CYD: no probes, no relays, no control loop.
# It subscribes to the controller's broadcasts and renders them, so the tank
# stays regulated whatever this board is doing.
#
# ---------------------------------------------------------------
# Why round changes the design rather than the dimensions
# ---------------------------------------------------------------
# 466x466 CIRCULAR. The CYD layout is a rectangular grid -- a header bar with
# radio icons at its ends, cards left and right, nav buttons along the bottom.
# Every one of those lives in a corner that physically does not exist here.
# None of it ports.
#
# So everything below is positioned with LVGL's align: system -- CENTER,
# TOP_MID, BOTTOM_MID with offsets -- and NOT absolute x/y. The CYD layout is
# hard-coded to 320x240, which is precisely why moving to this panel is a
# rewrite instead of a resize. Doing it the same way again would just move
# that debt to the next screen.
#
# The constraint helps. At ~44.5mm across and 466px the pitch is 0.095mm,
# roughly twice as fine as the CYD, and a round face has no room for
# furniture -- so one big centred number gets the space the CYD spends on
# chrome. That is the readability the whole panel exists for.
#
# ---------------------------------------------------------------
# Verified, not assumed
# ---------------------------------------------------------------
# Pins are from Waveshare's own HARDWARE_REFERENCE.md. CS=12 and RESET=39
# independently match ESPHome's built-in preset, which cross-validates it.
#   QSPI: SCLK 38, D0 4, D1 5, D2 6, D3 7, CS 12, RESET 39
#   Touch I2C: SDA 15, SCL 14, INT 11, RST 40  (CST9217)
#
# CST9217 is handled by ESPHome's cst9220 driver -- that driver explicitly
# accepts both 0x9220 and 0x9217 chip ids, so this is supported rather than
# hopeful.
#
# PSRAM is MANDATORY: the framebuffer is 466*466*2 = 424 KB and cannot live
# in internal RAM. The model preset carries requires={"psram"}, so a board
# without it fails at config time rather than mysteriously at runtime.

esp32:
  board: esp32s3box
  variant: esp32s3
  flash_size: 16MB
  framework:
    type: esp-idf
    sdkconfig_options:
      # Let Wi-Fi and LWIP allocate from PSRAM instead of internal RAM.
      #
      # Measured on this board 2026-09-23, one minute after boot: 43 KB of
      # internal heap free at startup, and 26 KB once BLE, MQTT and the web
      # server had connected -- with a largest contiguous block of 13.5 KB.
      # Meanwhile 8.37 MB of the 8 MB PSRAM sat unused, because only the
      # framebuffer lives there.
      #
      # 13.5 KB of contiguous internal RAM is not enough headroom for this
      # board's workload. The ESP-IDF Wi-Fi stack allocates DMA-capable
      # internal RAM for its RX/TX buffers, and it does so at exactly the
      # wrong moments -- a reassociation, a roam, a burst of traffic. An
      # allocation failure there does not politely retry; it aborts or
      # wedges the Wi-Fi task, which is the "offline until physically
      # unplugged" signature this panel started showing.
      #
      # This moves the Wi-Fi and LWIP buffers into PSRAM, where there are
      # megabytes to spare. PSRAM is slower than internal SRAM, but these
      # are network buffers on a display-only panel -- there is nothing
      # here that needs the latency, and the framebuffer DMA is unaffected.
      CONFIG_SPIRAM_TRY_ALLOCATE_WIFI_LWIP: "y"

# ESPHome's default MQTT unique_id generator is "legacy": "ESP" + component
# type + object_id, with NO device name and no MAC in it. So this board's
# "Water Temperature" generates a unique_id byte-identical to the C6's, and
# Home Assistant refuses to register a second entity with a unique_id it
# already holds -- silently, with nothing in the log. The symptom is that
# only the entities the OTHER board does not have ever appear.
#
# This lives in the BOARD FILE, not the wrapper. The wrapper is the one file
# not pulled from git, and putting load-critical config there has silently
# failed four times in this project now.
mqtt:
  discovery_unique_id_generator: mac


psram:
  mode: octal
  speed: 80MHz

# PSRAM free, on top of the internal-heap diagnostics in base.yaml. This
# board is the only one that allocates out of PSRAM in bulk (the 424 KB
# framebuffer), so it is the only one where PSRAM exhaustion is a way to
# die -- and internal Heap Free would look healthy the whole way down.
sensor:
  - platform: debug
    psram:
      name: "PSRAM Free"
      entity_category: diagnostic

spi:
  - id: amoled_bus
    type: quad
    clk_pin: GPIO38
    data_pins: [GPIO4, GPIO5, GPIO6, GPIO7]

i2c:
  - id: touch_bus
    sda: GPIO15
    scl: GPIO14
    scan: true
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

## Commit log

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2026-08-23 Add a purpose-built enclosure for the LAFVIN board
    No off-the-shelf case fits: the Waveshare-outline and generic MakerWorld
    ESP32-C6 enclosures assume a centred LCD with USB on a long edge, but this
    board is a stick with USB-C, BOOT and RESET on one short end.
    Parametric OpenSCAD plus tray/lid/fit-test STLs. LAFVIN publishes no
    mechanical drawing, so dimensions came off photographs and are good to
    about +/-1mm -- the design absorbs that rather than pretending otherwise:
    full-width USB slot instead of a shaped port, LCD window cut 1mm inside
    the glass so the bezel hides positional error, and no BOOT/RESET holes
    since those positions are the least certain and OTA makes them unneeded.
    Ships a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
    [tank-monitor-case.scad, tank-monitor-fittest.stl, tank-monitor-lid.stl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]
2026-08-23 Fix fan pin and cable exits from the board's actual header layout
    A photo of the board's underside shows the broken-out pins, and GPIO10 --
    which the fan output was assigned to -- is not among them. That would have
    failed silently: wiring complete, fan channel dead, no error anywhere.
    Moved to GPIO3. Avoided GPIO22 (exposed but also the LCD backlight net),
    GPIO13 (USB D+) and GPIO9 (boot strapping).
    The headers run down both long edges, so wires leave from the sides rather
    than off the end. Case now has a 26x5mm slot on each long side over the
    header rows, replacing the single end slot.
    Documents the full list of physically available pins, since the board's
    usable set is much smaller than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
    [tank-monitor-case.scad, tank-monitor-fittest.stl, tank-monitor-lid.stl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]
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2026-08-23 Add a fit gauge; stop estimating board width from photos
    The first coupon printed too loose. Every dimension in the case came from
    scaling the same set of photographs, so re-measuring them cannot find the
    error -- it just reproduces it.
    fit-gauge.stl is six pockets from 21.0 to 23.5mm in 0.5mm steps, each
    stamped with its size. Whichever grips is the real width, measured by
    trying rather than by inference. Five minutes to print.
    [fit-gauge.scad, fit-gauge.stl]
2026-08-23 Tighten the pocket 0.5mm after the first coupon printed loose
    pcb_w 23.0 -> 22.6, so the pocket goes 23.8 -> 23.4mm. Length trimmed
    51.0 -> 50.0 to match what the photos actually showed.
    Still an estimate, just a smaller one -- fit-gauge.stl is what settles it.
    [tank-monitor-case.scad, tank-monitor-fittest.stl, tank-monitor-lid.stl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]
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2026-08-26 Stop the feedforward commanding heat into an already-warm tank
    The controller was holding the heater at 29% with the water above
    setpoint and its own drift sensor reading 0.00 degF/h. Model Confidence
    was 24%, so the trust weighting was letting through a passive estimate
    of -3.3 degF/h against a tank that was, measurably, not moving. The
    feedforward came out 4x the size of the measured error, pointing the
    opposite way.
    Confidence counts learning steps, not learning. It saturates in a day,
    while theta[2] and theta[4] -- the two parameters behind the passive
    term -- need several days, and theta[4] is nearly unidentifiable while
    the tank holds still. Authority was granted on a schedule, not ev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
    [control.yaml]
2026-08-26 Move the CYD to mipi_spi so its display can actually allocate
    ili9xxx keeps a single 320*240*2 = 154kB framebuffer and has no
    partial-buffer mode. This board has no PSRAM, and the build leaves
    roughly 125kB of the tracked DRAM segment once statics are placed --
    before Wi-Fi and MQTT take theirs. On a failed allocation the component
    calls mark_failed(), so the screen would simply never appear while every
    other component ran normally. A quiet failure, and one that would have
    been diagnosed with the board in hand instead of before ordering.
    mipi_spi renders in stripes, so buffer_size: 50% fits with room to
    spare. The cost is the lambda running once per stripe, re-rasterising
    the 134px font eac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
    [cyd-esp32-2432s028r.yaml]
2026-08-26 Cap the integral at 30% duty, and back out the trust-by-fit change
    The overshoot has a simpler cause than I claimed, and the evidence for
    the previous commit's reasoning does not survive contact with the
    recorder.
    WHAT ACTUALLY HAPPENED. The tank ran 39 minutes at 100% duty and carried
    75.8 F to 77.8 F against a 76.0 F setpoint. Working backwards through
    the control law: ki is 1/response_time^2, so with a 30 min response the
    integral saturates its old flat +/-0.05 degC/min clamp within about 90
    minutes of any sustained cold error. At the learned kh of 0.032 that
    saturated integral is worth 158% heater duty on its own. It can hold the
    heater wide open until the proportional term alone outwei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
    [control.yaml]
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2026-08-26 Give the setpoint one owner, and stop the fan saturating on a 0.66F error
    Four bugs, all surfaced by one reboot.
    SETPOINT HAD TWO OWNERS. The Target Temperature number was optimistic
    with restore_value, so it persisted its own copy while tank_controller
    persisted setpoint_pref_ separately. On boot the number restored its copy
    and pushed it in, so whichever was written last silently won. They had
    diverged -- the controller reporting 76.0 F while the number held 73.9 --
    and after the flash the number won. The tank sat at 76.55 being actively
    cooled toward 73.9 with the fan wide open, and nothing on any dashboard
    said the target had moved.
    The controller already persists the setpoint and is t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
    [control.yaml]
2026-08-26 Add a fan-stall check, publish the learned fan gain, say what Output means
    Heater Output and Fan Output are the controller reading back its own
    command. No current sensing, no contact feedback, nothing confirming the
    relay closed or that the outlet has anything plugged into it. They are
    ordinary controller-output terms, but with a % and state_class:
    measurement they read as evidence -- and they are not. That cost an
    evening: a heater that had stopped delivering showed 90-97% on the graph
    throughout, and only the water falling against a model that said it
    should climb gave it away.
    Nothing here renames those entities. "Controller output" is the standard
    term and means exactly this; the mista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
    [control.yaml]
2026-08-26 Make the display bands follow the setpoint instead of fixed temperatures
    The six colour thresholds were absolute Fahrenheit values tuned for a
    76.0 F target. Lower the target from Home Assistant and the colours kept
    describing the old one -- the screen would call a tank held perfectly at
    74.5 "TOO COLD" while the controller sat happily on setpoint.
    They are now offsets from the setpoint, read live at render time rather
    than baked in at compile time. Nothing to keep in sync by hand and no way
    for the colours to describe a target the tank is not being held at.
    The offsets reproduce the previous bands exactly at 76.0 F, including the
    deliberate asymmetry -- more usable room below target than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
    [cyd-esp32-2432s028r.yaml]
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2026-08-27 Stop the display passing judgement on TDS
    The bottom strip coloured TDS green inside 180-250 ppm and red outside
    300. This tank sat at 489 ppm with GH 1.7 dGH -- mineral-starved water
    that any TDS threshold would have called an emergency for the wrong
    reason, and which is now correctly remineralised at a similar number and
    was still showing red.
    TDS is the sum of everything dissolved. The same 450 ppm is a properly
    remineralised tank or one full of sodium and nitrate with no usable
    hardness, and no threshold can tell those apart. GH and KH carry that
    verdict, as test-kit values in Home Assistant with adjustable targets.
    The strip now reports the number on a neutral background and colours o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
    [cyd-esp32-2432s028r.yaml]
2026-08-27 Rebuild the CYD screen on LVGL: three touch pages
    The hand-drawn lambda is replaced with an LVGL UI on this board only. The
    C6's screen is untouched -- different board file, no shared display code.
    LVGL is the right tool here and the wrong one there. This panel is 320x240
    with an XPT2046 touchscreen, and LVGL brings real compositing: gradients,
    alpha, anti-aliased radii, drop shadows, animated widgets. The C6 is a
    320x172 strip with no touch and a layout already tuned to be read across a
    room; LVGL there would cost flash and buy nothing.
    Home: an arc gauge spanning the full setpoint-relative band, recoloured
    live through the same blue-to-red ladder the C6 uses, with the reading in
    the cent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
    [cyd-esp32-2432s028r.yaml]
2026-08-27 Mirror water chemistry to the CYD over retained MQTT, cached in flash
    pH, free ammonia, GH, KH, NO2 and NO3 are values this device cannot
    measure -- they come from the Seneye and from a test kit typed into Home
    Assistant. An HA automation now republishes them to retained topics under
    tank-monitor/chem/, and the CYD subscribes.
    Retention alone would not be enough. The broker lives on the Home
    Assistant host, so if HA is down the broker is too, and a device that
    rebooted in that window would show nothing. Every value is therefore also
    mirrored into a restore_value global and stamped with its arrival time.
    The display reads the globals, never the live subscription, so the panel
    always shows th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
    [cyd-esp32-2432s028r.yaml]
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2026-08-27 Give the CYD its own device_name, and make its touchscreen usable
    Two separate faults, both mine, both from the same habit of not revisiting
    an assumption after the thing it depended on changed.
    device_name was left shared, so both boards booted as "tank-monitor" and
    published to identical MQTT topics with identical discovery object ids.
    They overwrite each other as fast as they appear, which presents as
    entities silently going missing rather than as a name clash. Now
    tank-monitor-v2, which also separates the mDNS hostname, the fallback AP
    and the LWT topic.
    The wrapper's comment claimed a second device needs its own
    tank_monitor_cyd_* secrets. It does not: base.yaml references fixed secre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
    [cyd-esp32-2432s028r.yaml]
2026-08-27 Fix the CYD's entities never appearing in Home Assistant
    The device was publishing all 39 entities correctly -- confirmed by
    reading its own event stream -- but only 7 reached Home Assistant, and
    those 7 were exactly the chemistry sensors.
    ESPHome's default MQTT unique_id generator is "legacy": "ESP" +
    component_type + object_id, containing neither the device name nor the
    MAC. Two boards built from the same packages therefore publish identical
    unique_ids -- "ESPsensorwater_temperature" on both -- and Home Assistant
    drops the duplicate registration without an error. The chemistry sensors
    got through because they are the only entities the C6 does not also have.
    Renaming the device to tank-mo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
    [cyd-esp32-2432s028r.yaml]
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2026-08-27 Move model migration into control.yaml and make it observable
    The seed subscriptions were in an opt-in package, and that failed twice in
    a row for the same reason: the board wrapper is the one file NOT pulled
    from git, so "add this line to your wrapper" is a step that silently does
    not happen. The device then looks completely healthy and quietly ignores
    the retained seed -- no error, no missing entity, nothing to notice.
    Now in packages/control.yaml, which every board already loads. Cost is six
    MQTT subscriptions and seven globals. Topics stay device-scoped
    (<device_name>/seed/...), so two boards cannot seed each other, and a
    board with nothing retained on its topics never fires.
    Adds a Se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
    [control.yaml]
2026-08-28 Move seed topics out from under the device's own MQTT topic_prefix
    The v2 ran firmware with the seed subscriptions compiled in -- verified
    in main.cpp -- connected to the same broker as everything else, and
    received nothing on tank-monitor-v2/seed/*. Six retained publishes and
    six live ones, across two reflashes, produced no reaction at all.
    On the same connection, at the same time, the device received
    tank-monitor/chem/ph and updated the cached value. So inbound MQTT
    works; the subscription itself is the thing that never delivered.
    The only variable that separates the two cases is whether the topic sits
    under the device's mqtt topic_prefix. chem does not; seed did. Moving
    the seed topics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
    [control.yaml]
2026-08-28 Collapse the model seed to one topic and make the payload visible
    Moving the seed topics out of the device's topic_prefix did not fix the
    migration: a retained publish to tank-seed/tank-monitor-v2/heater_f_per_h
    still produced no reaction. Six subscriptions, six chances to fail, and
    no way to see which had -- Seed Status could only report "idle", which is
    also exactly what a stale build reports.
    Two changes, both aimed at making the next attempt conclusive rather than
    at another guess about the mechanism:
    Seed Payload is a non-internal mqtt_subscribe text_sensor carrying the
    raw payload. Whether the device received anything is now something to
    look at rather than infer from a derived count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
    [control.yaml]
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2026-08-28 Rotate the CYD panel in hardware so touch and layout share a frame
    A tap on HOME reported x=217 y=294. A y of 294 cannot exist on a
    240-tall canvas, which rules out the mirror/swap flags entirely: those
    flip and swap axes, they cannot rescale 240 into 320. The fault was
    scale, not handedness, so no combination of the three booleans would
    ever have converged -- and the previous comment invited exactly that
    search.
    LVGL's rotation: 90 rotates the composited layer and leaves the display
    reporting its native 240x320. The touchscreen takes its dimensions from
    the display, so touch ran in portrait while every widget was laid out in
    landscape.
    Rotation moves to the panel's MADCTL. The display now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
    [cyd-esp32-2432s028r.yaml]
2026-08-28 Use MADCTL MV alone for landscape; restore the touchscreen swap
    The previous commit rendered the UI as a reflection. Two mistakes, both
    from reasoning about the transforms instead of reading how they compose.
    The display transform replaces the model's defaults outright rather than
    adding to them -- get_base_transform takes config over defaults -- and
    the ILI9341 driver defaults to mirror_x=True for portrait. Writing
    swap_xy + mirror_x therefore produced MADCTL MV|MX: a transpose plus a
    mirror, which is a reflection, not a rotation. The ILI9341 set is MX
    portrait, MV landscape, MY portrait-180, MX|MY|MV landscape-180, so
    landscape is swap_xy alone.
    MV keeps the orientation the LVGL-rotated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
    [cyd-esp32-2432s028r.yaml]
2026-08-28 Add the glyphs the CYD UI renders but the fonts omitted
    Three characters were drawn as placeholder boxes: '&' in the WATER &
    MODEL header, '/' in "uS/cm" and "F/h", and '+' on the setpoint button
    and in the %+ drift sign.
    Found by extracting every literal the board renders -- including the
    signs a printf conversion can emit, since "%+.2f" produces '+' as well
    as '-' -- and checking each against the face its label resolves to. That
    resolution is not always local: the header and the EC readout take their
    font from the caption style rather than a text_font key, so '&' and '/'
    were needed in font_sm and '/' and '+' in font_md.
    A missing glyph does not fail the build. LVGL substitutes a box and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
    [cyd-esp32-2432s028r.yaml]
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2026-08-28 Re-pin the CYD to the connectors this board revision actually has
    A photo of the board shows the headers are: 3.3V/IO35/GND, an SPI header
    carrying IO23/IO19/IO18/IO27, and a UART header carrying RXD/TXD/GND/5V.
    IO22 is not broken out at all, so the DS18B20 was assigned to a pin that
    does not exist on this hardware. IO18/19/23 are the microSD bus and the
    card is unused, which frees three GPIOs on the SPI header:
    fan IO26 -> IO18 (SCK)
    DS18B20 IO22 -> IO19 (MISO)
    heater IO27 unchanged (CS)
    TDS IO35 unchanged
    That also retires the speaker-header question. IO26 reaches the connector
    through the audio amplifier on this revision, so it could not have driven
    a relay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
    [cyd-esp32-2432s028r.yaml]
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2026-08-29 Make the CYD a display-only remote panel
    The CYD spends nearly every GPIO on its own screen and touch controller.
    Making it a second controller meant repurposing the microSD bus, hanging
    the light sensor off the pins the USB bridge uses to flash the chip, and
    metering the speaker header to learn whether it reached a pin or an
    amplifier. Each of those is a real constraint fighting a real
    requirement, and the last few days were spent losing that fight.
    Splitting the roles removes the class of problem rather than the current
    instance. The C6 keeps the probe, the relays and the control loop -- the
    tank stays regulated by hardware bolted to it, and keeps being regulated
    whether or not the panel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
    [cyd-esp32-2432s028r.yaml]
2026-08-29 Sync the panel's switch from the controller, and document dropped retains
    The Adaptive Learning toggle subscribed to the controller's state and
    then ignored it. The widget only ever showed what was last pressed on the
    panel, so it read "off" while the controller had learning enabled, and
    would have been wrong after any change made from Home Assistant or the
    controller's own web UI. The interval now drives the widget from the
    received state, guarded by r_sync so that syncing does not publish a
    command back and loop.
    Also records why the setpoint and that switch were the two things missing
    after the first flash while every sensor populated normally. ESPHome's
    ESP32 MQTT backend queues inbound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
    [cyd-esp32-2432s028r.yaml]
2026-08-29 Make dropped retained messages invisible rather than wrong
    The drops themselves cannot be fixed from here. On connect esp-mqtt emits
    a subscribed event and a data event per subscription, so ~20
    subscriptions produce ~40 events into a 32-slot queue drained one per
    loop iteration. The queue length is a compile-time constant. "Dropped 6
    inbound MQTT events" is the expected result and will keep appearing.
    What can be fixed is depending on that one delivery. The learning state
    lived in a text_sensor, which is empty after every boot, so a dropped
    retain left the toggle with nothing to show and it defaulted to off while
    the controller had learning enabled. It now lands in a restored global,
    so the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
    [cyd-esp32-2432s028r.yaml]
2026-08-30 Add battery level and runtime to the CYD panel
    Shows an icon, percentage and estimated time remaining bottom-right, on
    LVGL's top layer so it appears over every page rather than as three
    copies that drift out of sync.
    Drawn from plain objects, not a font glyph. The font sets here are
    trimmed to the characters actually used and a missing glyph renders as a
    box with no build error -- which has already happened twice in this
    project. A rectangle cannot go missing, and it can be filled
    proportionally, which a glyph cannot.
    Percentage comes from a piecewise LiPo curve rather than a linear map
    between 3.0V and 4.2V. A cell sits near 3.7V for most of its life and
    then falls off a cliff, so the li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
    [cyd-esp32-2432s028r.yaml]
2026-08-30 Show charging state on the battery indicator
    The first version only hid the runtime estimate when the pack started
    rising, so a charging pack at 60% looked identical to a discharging one
    at 60% that had not yet built a slope.
    No charge-status pin is broken out on this board, so the only available
    evidence is which way the voltage is going. Sampled every five minutes:
    a 500mA charge lifts a small cell roughly 0.03V in that window, which
    clears the ADC noise, where one minute would not. Expect up to ten
    minutes of lag after plugging in.
    The thresholds are asymmetric on purpose -- rising needs 20mV of real
    evidence, falling only needs 5mV, and between them the previous answer
    stands. A pack r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
    [cyd-esp32-2432s028r.yaml]
2026-08-30 Stage 2: link the panel to the controller over ESP-NOW
    The panel's data no longer depends on Wi-Fi or on Home Assistant. The
    broker runs on HA, so with MQTT as the only path, HA going down took the
    panel's readings with it -- and the panel is how you see the tank while
    standing in front of it. ESP-NOW is peer to peer: the controller keeps
    regulating and the panel keeps showing it with the router and HA both
    offline.
    Commands travel the same way. Sending setpoint changes over HTTP or MQTT
    would have left the buttons dead in exactly the outage this exists to
    survive, so the +/- buttons and the learning switch broadcast over
    ESP-NOW too. The controller validates the setpoint against the same
    7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
    [cyd-esp32-2432s028r.yaml]
2026-08-30 Show Wi-Fi and ESP-NOW link state on the panel and in Home Assistant
    Both link failures are silent. A channel change at the router or a key
    mismatch between the boards stops ESP-NOW with no error on either side,
    and the panel goes on showing whatever it last received. Nothing said so.
    On screen, top right of the home page: a Wi-Fi fan and an ESP-NOW
    broadcast symbol, green connected and red not. LIGHT moves to the middle
    of the header to make room. Drawn as arcs rather than glyphs, for the
    same reason as the battery -- the trimmed font sets render a missing
    glyph as a box with no build error.
    The two icons are deliberately independent rather than one "online"
    light. ESP-NOW is peer to peer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
    [cyd-esp32-2432s028r.yaml]
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2026-08-31 Step the panel's setpoint by 0.1 F, and repeat while held
    The buttons moved in 0.5 F jumps while the Target Temperature number
    entity has always used a 0.1 step, so the panel could not reach half the
    values Home Assistant could set.
    0.1 per tap is tedious across a whole degree, so holding a button now
    repeats at the panel's long_press_repeat_time -- about 1 F per second.
    The trigger is on_press rather than on_release because a long press fires
    release too, which would have added an extra step every time a hold
    ended.
    Both buttons now go through one script instead of two copies of the same
    lambda, so a tap and a hold cannot drift apart.
    The script clamps to 70-80 F as well as the controlle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
    [cyd-esp32-2432s028r.yaml]
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2026-09-02 Show the relays as ON/OFF on the panel, not as a duty percentage
    The heater and fan tiles led with a percentage, which reads as a fault.
    A plug has no partial setting, so "FAN 41%" while the fan is silent looks
    broken -- and at 41% duty over a 15 minute window it is silent for nine
    minutes out of every fifteen. Both readings were true and the display
    invited the wrong conclusion from them.
    The tiles now lead with the actual relay contact state, coloured amber
    for heat and blue for cooling, with the commanded duty kept as the
    unlabelled bar underneath. That keeps the information that the controller
    is working without a number that has to be explained every time it is
    read.
    This required bro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
    [cyd-esp32-2432s028r.yaml]
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
